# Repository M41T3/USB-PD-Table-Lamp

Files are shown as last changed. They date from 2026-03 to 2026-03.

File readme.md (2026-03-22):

# Table Lamp with USB PD Light Controller

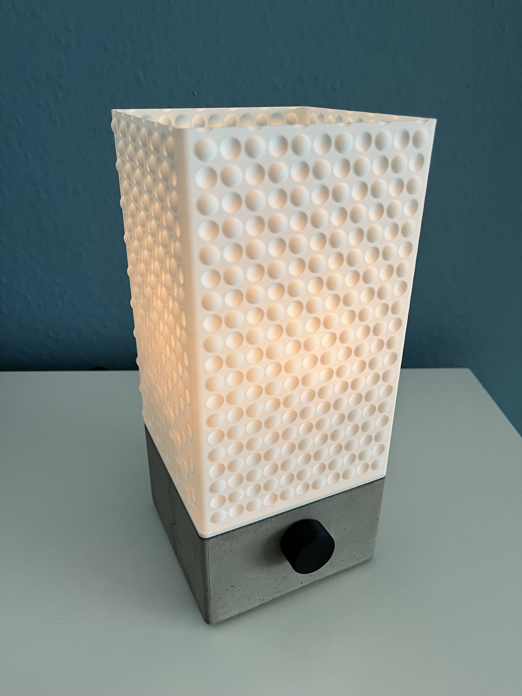
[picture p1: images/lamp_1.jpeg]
lamp


## Contents

- Light controller PCB design
    - [Schematics](light_controller_pcb/light_controller_base/schematics.pdf)
    - [PCB design](light_controller_pcp/light_controller_base/pcb.pdf)
    - KiCad project
    - JLCPCB production files
- CAD designs (FreeCAD projects)
    - concrete lamp base mould
    - shade, light mount and knob

## 1. PCB design

The objective was to develop a highly configurable controller for various light sources that is powered via USB Power Delivery.

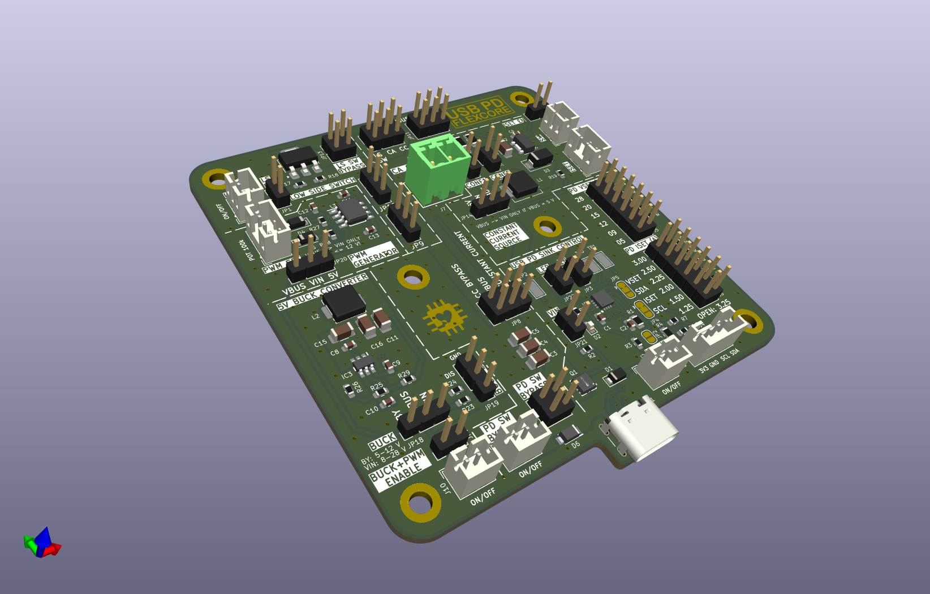
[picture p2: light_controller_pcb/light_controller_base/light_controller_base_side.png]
pcb


### Operation Modes

The operating mode can be configured using jumpers and potentiomenter wiring: 

1. Switch VBUS power and dimm light via PMW
2. Switch VBUS power and dimm light via constant current source
3. Low Side Switch and dimm light via PWM
4. Simple ON/OFF with disabled USB PD (5 V)
5. Switch VBUS power and fixed output current (set with jumpers)

### Noteable Features
- Configure output voltage and current 
    - Voltage: 5 V, 9 V, 12 V, 15 V, 20 V, 28 V
    - Current: 1.25 A - 3.25 A
    - Low power LED up to high power halogen lamps (35 W) supported
- Step-down converter to supply control units with all voltage levels
- Dimm light with PWM (555 Timer module)
- Constant current source to fine tune current 
- High power mosfet to switch light 
- 80 x 80 mm

#### USB PD ERP Sink controller ([HUSB238A](https://www.lcsc.com/datasheet/C24833806.pdf)):

- Fully Autonomous USB Type-C® and USB PD Sink Controller
- USB PD Specification Reversion 3.1 supported
- Integrated VBUS Switch Driver
- Error detection output (LED)

#### PWM Controller ([LMC555](https://www.lcsc.com/datasheet/C90760.pdf))

- CMOS variant of famous 555 general-purpose timer
- Duty cycle configurable by 100k potentiometer 

#### Constant Current Source ([PAM2861](https://www.lcsc.com/datasheet/C150496.pdf))

- 1 A LED driber with internal switch
- Adjustable output current (100k potentiometer)

#### Step-Down Converter ([TPS54302](https://www.ti.com/lit/ds/symlink/tps54302.pdf))

- Converts variable VUSB voltage to 5 V to supply 555 timer and constant current control

#### 100 kOhm Potentiometer with Rotary Switch ([WSFA202-A2-08-30F1](https://asset.conrad.com/media10/add/160267/c1/-/en/000441431DS01/tehnicni-podatki-441431-potenciometer-z-10-a-stikalomweltron-wsfa202-a2-08-30f1-10k-20-lin-10-kiloo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))

## 2. Concrete Lamp Base

The lamp's base was made of concrete. To do this, a mold was designed and printed using a 3D printer with PLA. The controller board is installed inside the lamp's base.

### Mould

The mold is designed so that it can be taken apart into separate pieces after curing.

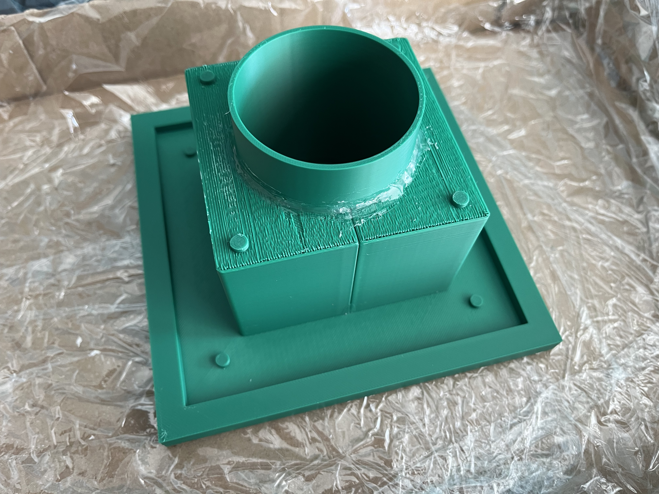
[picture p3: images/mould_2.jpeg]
inner mould


The seams are sealed with hot glue.

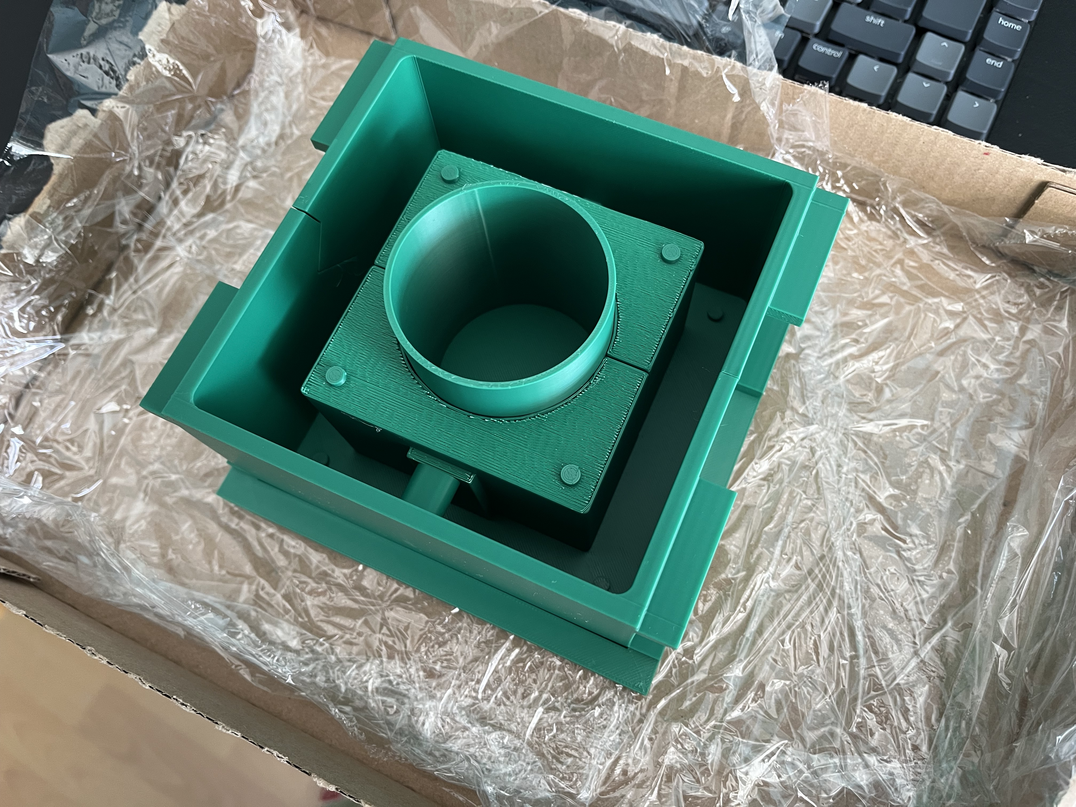
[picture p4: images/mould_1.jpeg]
complete mould


The liquid concrete is poured into the mold up to the top edge:

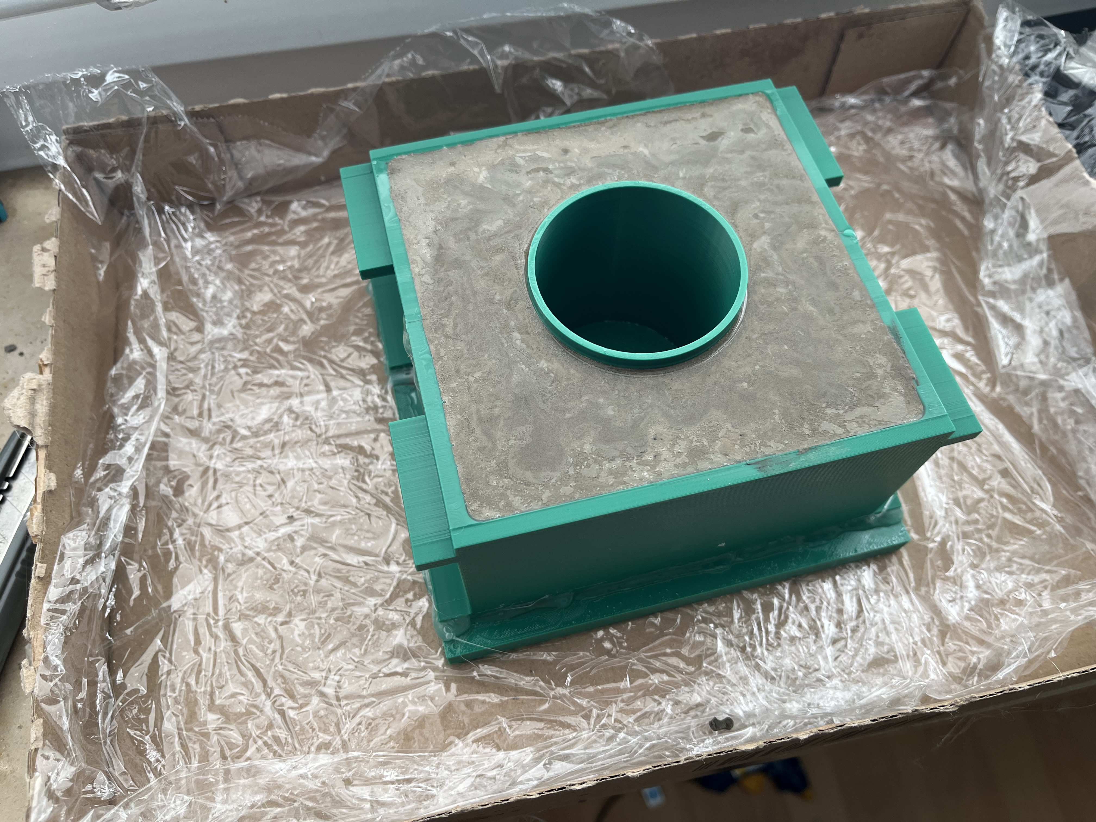
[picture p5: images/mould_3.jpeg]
filled mould


### Box of Shame
To be honest, it took three attempts with different modifications to the base design before I was able to get the concrete piece out of the mold in one piece...

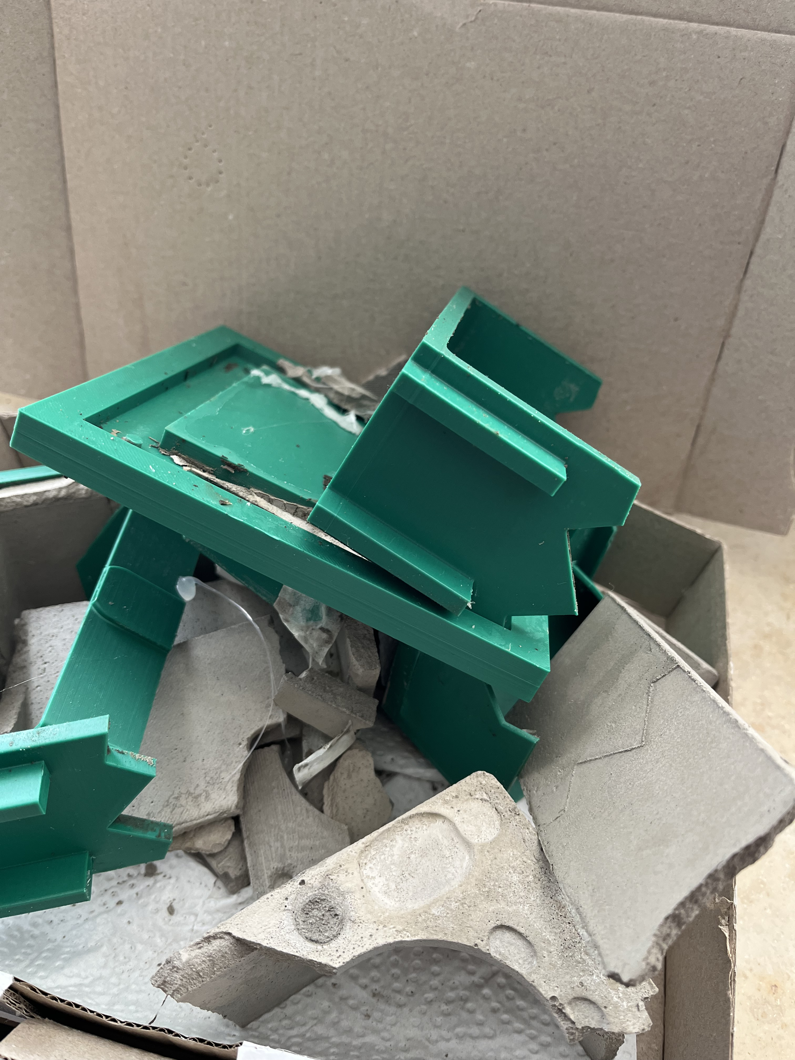
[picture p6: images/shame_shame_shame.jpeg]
box of shame


### Base installations

To position the light source in the right spot, a 3D-printed bracket is screwed onto the circuit board: 

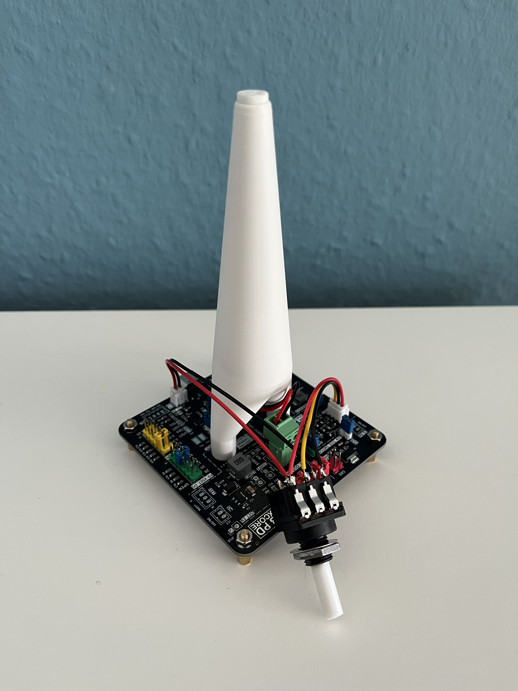
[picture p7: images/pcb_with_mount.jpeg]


PCB, potentiomenter, knob and magnets are installed to the base:

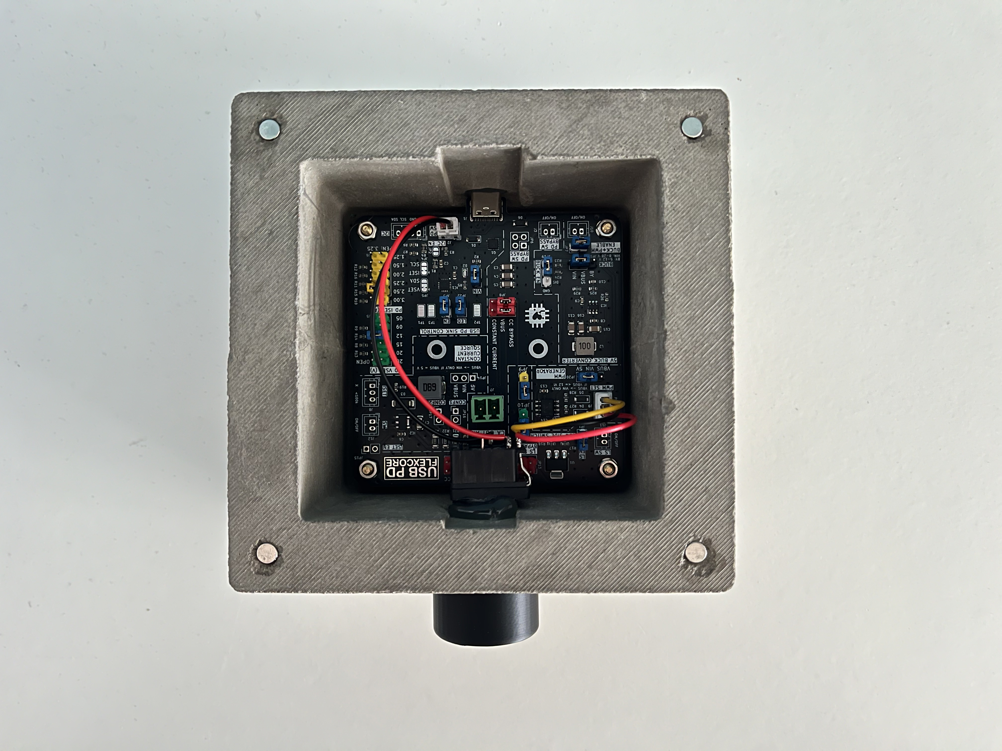
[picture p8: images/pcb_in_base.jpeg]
pcb in base


Bottom: 

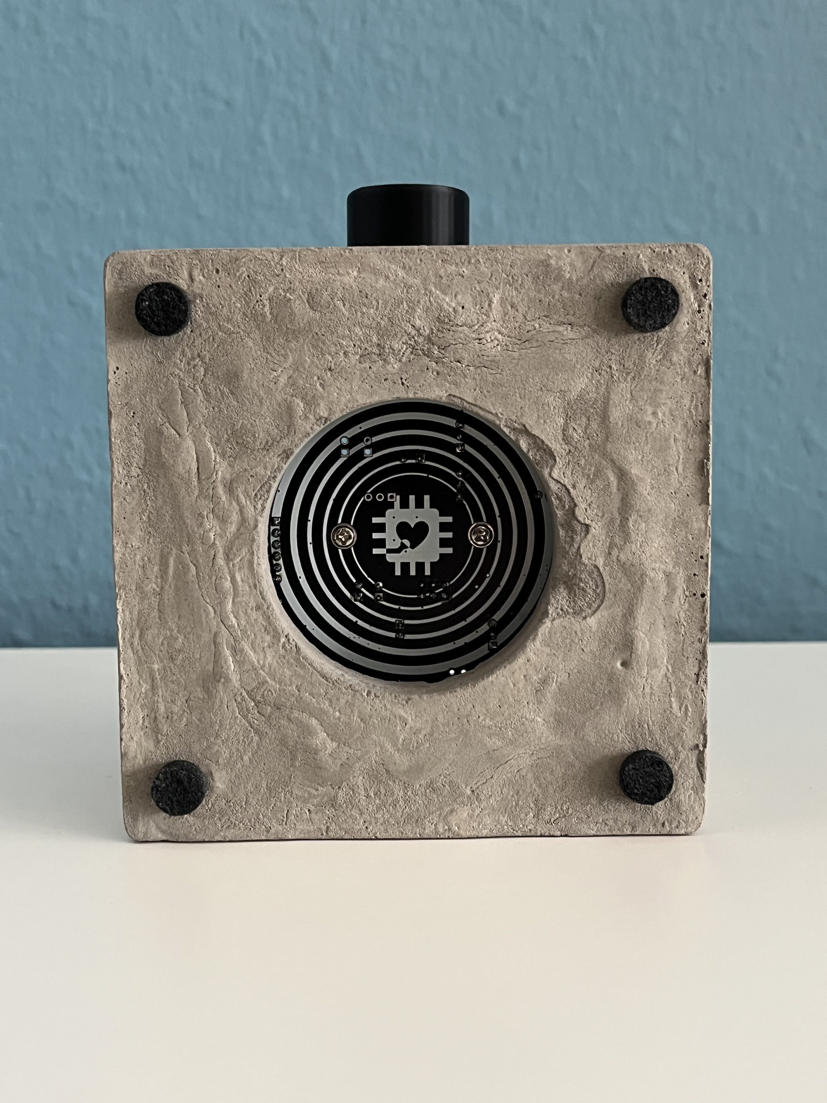
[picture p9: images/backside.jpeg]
pcb backside


## 3. Shade

The lamp base was designed so that the light shade can be attached using magnets. This means the shade can be easily swapped out. This shade was designed so that it can be 3D-printed in vase mode.

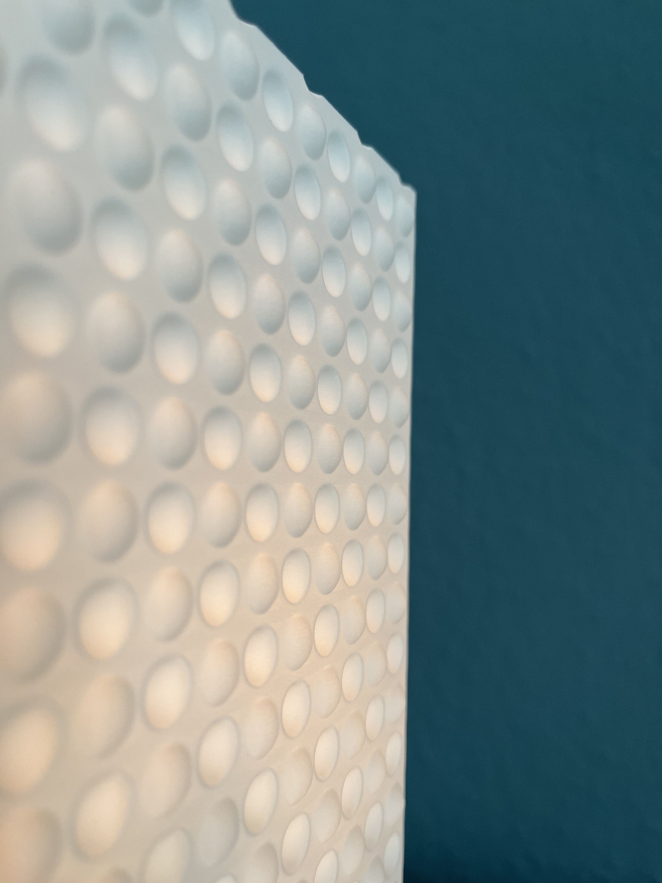
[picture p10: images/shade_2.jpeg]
shade

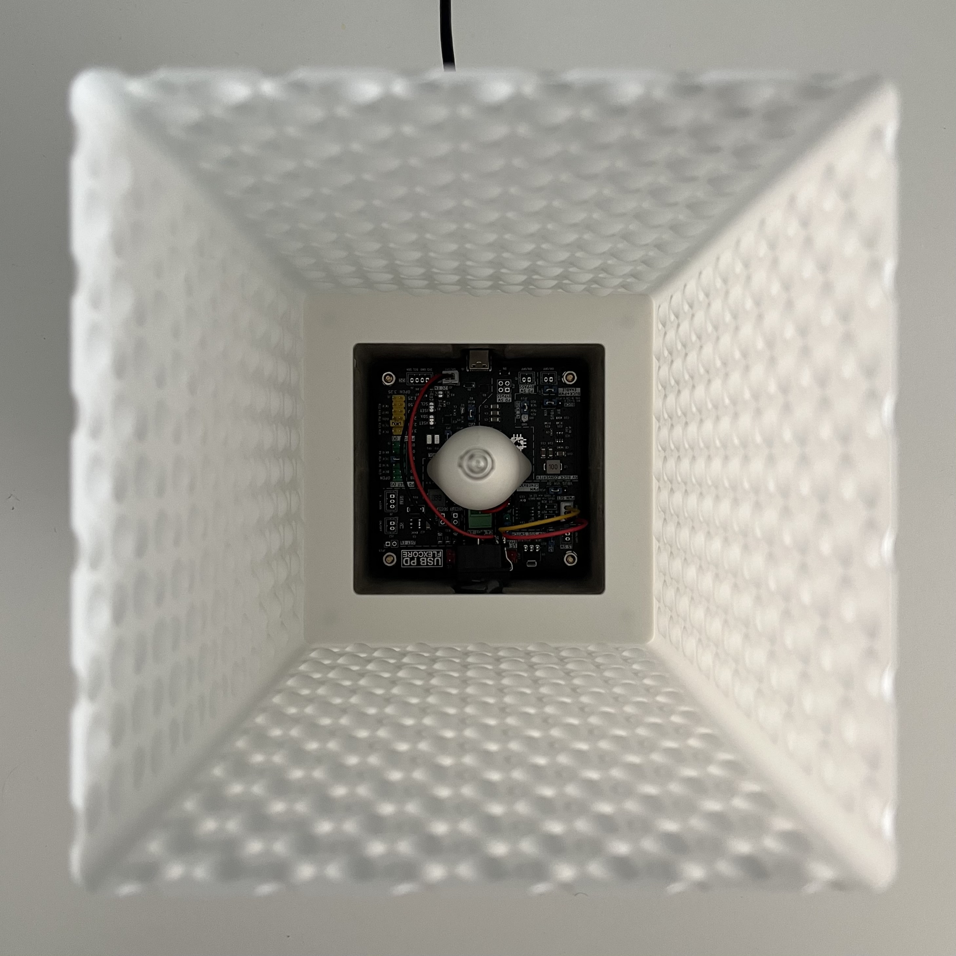
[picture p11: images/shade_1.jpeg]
shade detailed


## 4. Light it up!

Operating Mode: Switch VBUS and dimm light via PWM with potentiometer

lamp gif

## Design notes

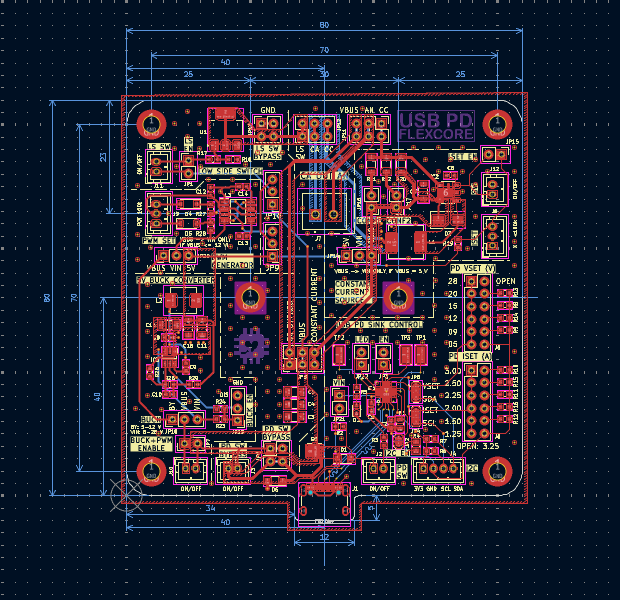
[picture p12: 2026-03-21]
light_controller_pcb/light_controller_base/pcb_design.png

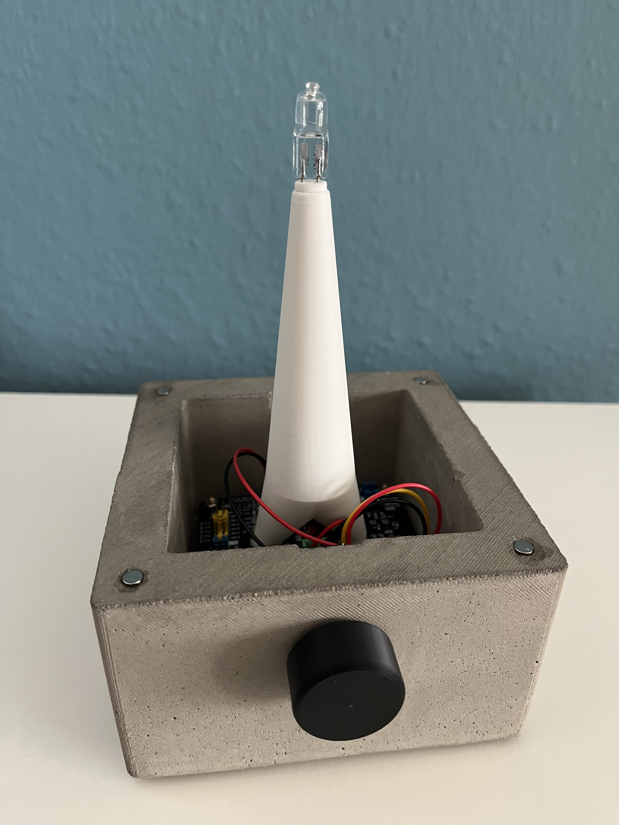
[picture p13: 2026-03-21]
images/lamp_wo_shade.jpeg

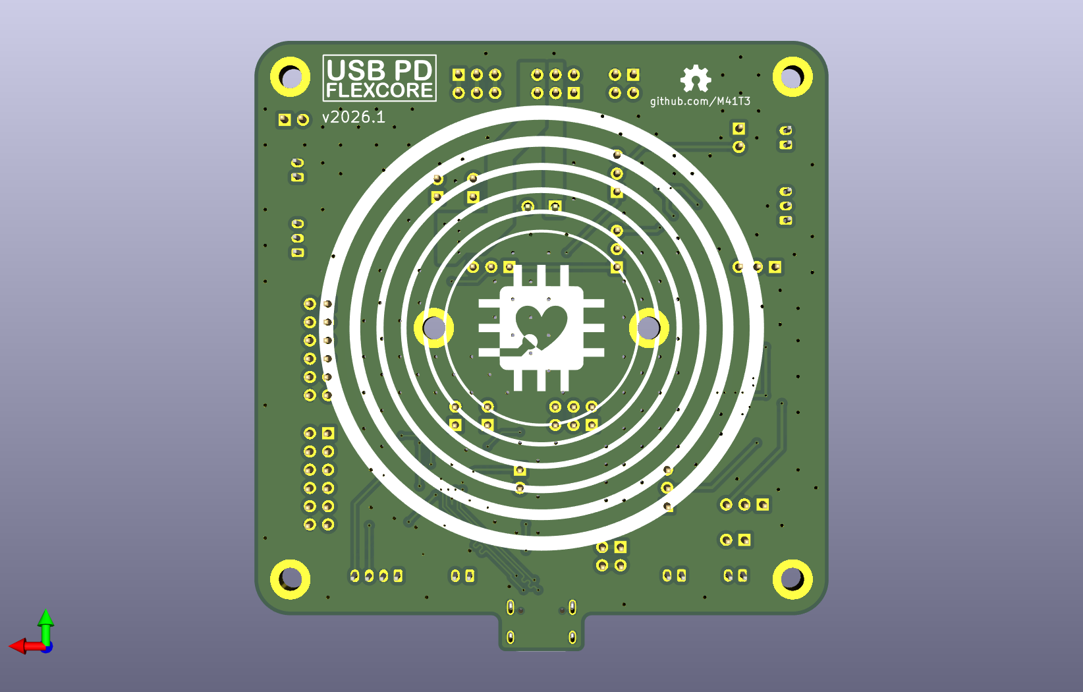
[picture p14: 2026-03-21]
light_controller_pcb/light_controller_base/light_controller_base_bottom.png

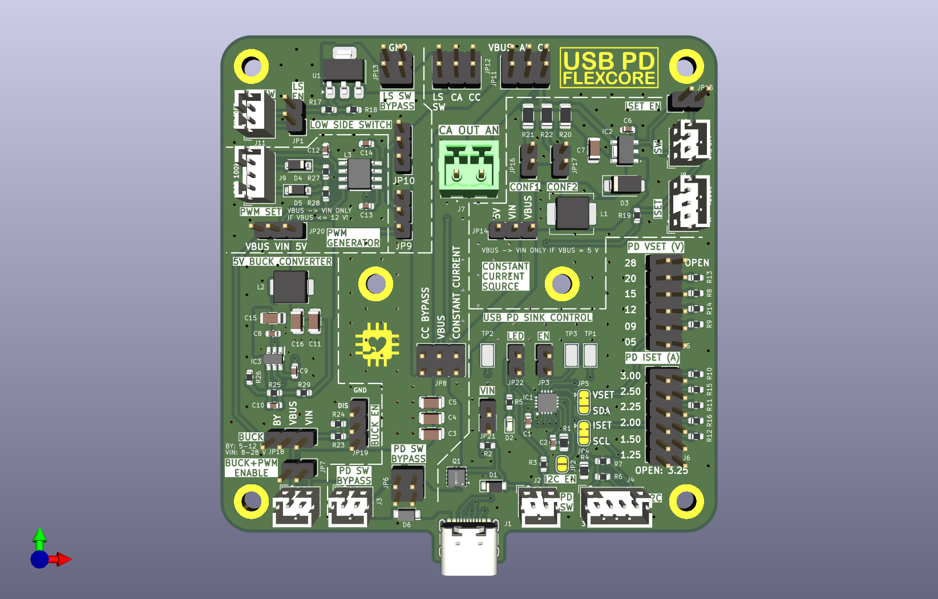
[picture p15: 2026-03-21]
light_controller_pcb/light_controller_base/light_controller_base_top.png

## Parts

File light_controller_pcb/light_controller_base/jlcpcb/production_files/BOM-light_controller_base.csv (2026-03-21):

Comment | Designator | Footprint | LCSC | Quantity
0.1 uF | C14 | C_0603_1608Metric | C14663 | 1
0.3 | R20,R21,R22 | R_1206_3216Metric | C59882 | 3
1 uF | C1,C2 | C_0603_1608Metric | C15849 | 2
1.8k | R5 | R_0603_1608Metric | C4177 | 1
10 nF | C12,C13 | C_0603_1608Metric | C57112 | 2
10 uF | C15,C7 | C_1206_3216Metric | C13585 | 2
10 uH | L2 | L_5.2_5.4_smd | C351099 | 1
100 nF | C8,C9 | C_0603_1608Metric | C14663 | 2
100k | R19,R25 | R_0603_1608Metric | C25803 | 2
105k | R24 | R_0603_1608Metric | C16840 | 1
10k | R6,R7 | R_0603_1608Metric | C25804 | 2
10nF | C6 | C_0603_1608Metric | C57112 | 1
11.5k | R15 | R_0603_1608Metric | C25949 | 1
11k | R8 | R_0603_1608Metric | C25950 | 1
13.3k | R26 | R_0603_1608Metric | C25952 | 1
19.1k | R13 | R_0603_1608Metric | C22897 | 1
1k | R17,R27,R28 | R_0603_1608Metric | C21190 | 3
2.26k | R12 | R_0603_1608Metric | C22904 | 1
21k | R10 | R_0603_1608Metric | C22956 | 1
22 uF | C11,C16 | C_1206_3216Metric | C12891 | 2
3k | R9 | R_0603_1608Metric | C4211 | 1
4.7 uF | C3,C4,C5 | C_1206_3216Metric | C29823 | 3
49.9 | R29 | R_0603_1608Metric | C23185 | 1
49.9k | R18,R2 | R_0603_1608Metric | C23184 | 2
511k | R23 | R_0603_1608Metric | C23194 | 1
6.04k | R14,R16 | R_0603_1608Metric | C25977 | 2
6.2k | R3 | R_0603_1608Metric | C4260 | 1
68 uH | L1 | L_6.6_7.1_smd | C2983094 | 1
75 pF | C10 | C_0603_1608Metric | C1681 | 1
8.45k | R11 | R_0603_1608Metric | C163417 | 1
900k | R1,R4 | R_0805_2012Metric | C52209984 | 2
AONR21307 | Q1 | DFN_3X3_EP | C3277813 | 1
D_Small | D4,D5 | D_SOD-123 | C81598 | 2
LMC555CMX_NOPB | L3 | SOIC127P600X175-8N | C90760 | 1
MM1Z24W Zener 24V | D1 | Nexperia_CFP3_SOD-123W | C2856870 | 1
NCE6005AR custom | U1 | SOT-223-3_TabPin2 | C189606 | 1
PAM2861CBR | IC2 | SOT89-5 | C150496 | 1
SMF33A | D6 | SODFL3618X110N | C353288 | 1
SS14 | D3 | D_SMA | C2480 | 1
TPS54302DDCR | IC3 | SOT95P280X110-6N | C311983 | 1
USB_C_Receptacle_USB2.0_16P | J1 | USB_C_Receptacle_GCT_USB4105-xx-A_16P_TopMnt_Horizontal | C165948 | 1
husb238a | IC1 | QFN50P300X300X80-17N-D | C24833806 | 1
~ | D2 | LED_0603_1608Metric | C2286 | 1

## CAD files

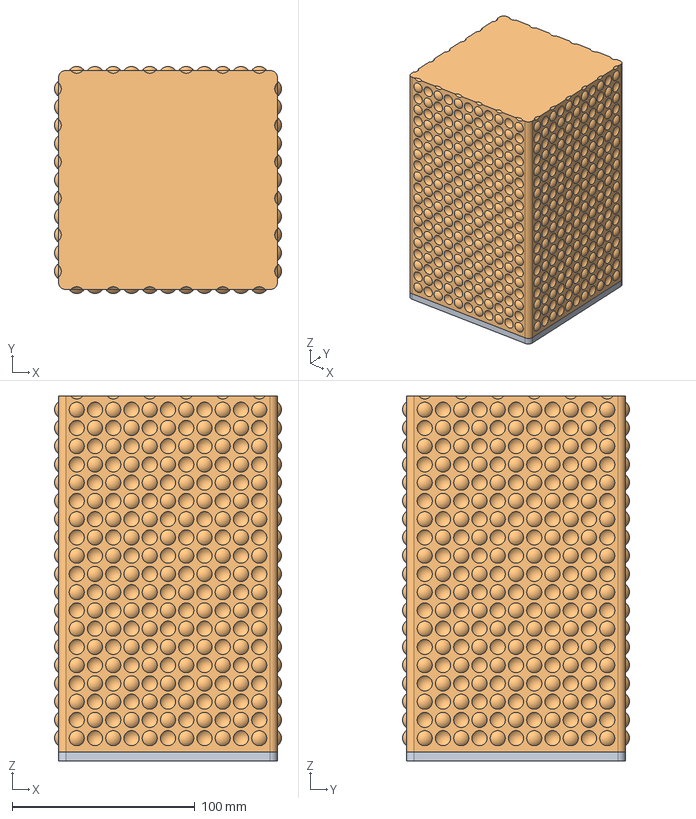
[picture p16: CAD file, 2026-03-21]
cad/shade_bubble_v2/shade_bubble_v2.step
124.4 x 124.4 x 200.0 mm
shade_base_w_mag

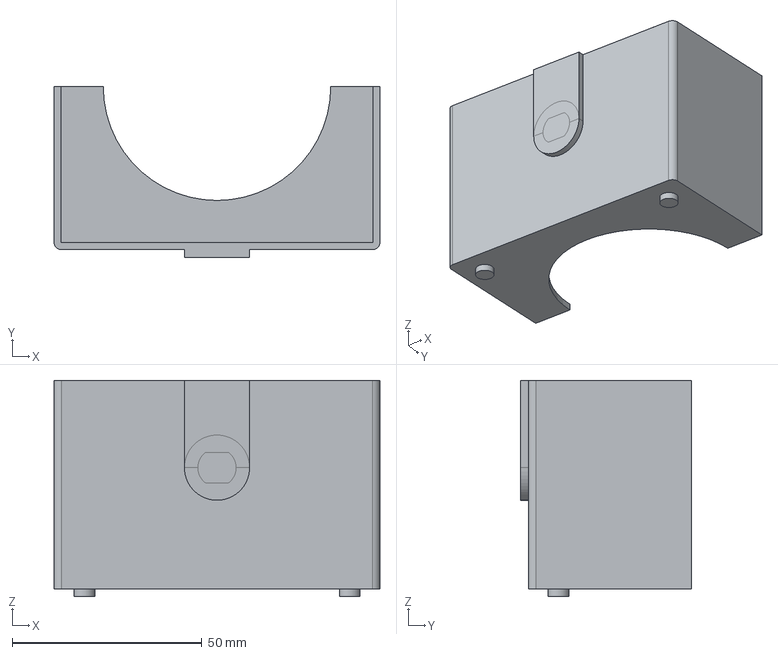
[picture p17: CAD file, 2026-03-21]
cad/usb_table_lamp-mould-mid-inf-thick.step
86.0 x 45.0 x 57.0 mm

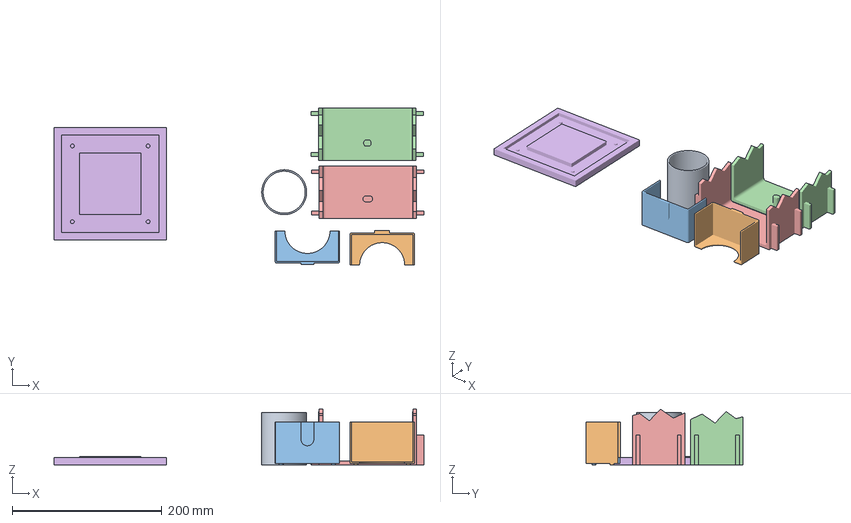
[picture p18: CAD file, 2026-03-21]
cad/usb_table_lamp-thick.3mf
493.5 x 209.8 x 74.3 mm
usb_table_lamp-mould-mid-cyl-thick.step
usb_table_lamp-mould-mid-inb-thick.step
usb_table_lamp-mould-mid-inf-thick.step
usb_table_lamp-mould-mid-b-thick.step
usb_table_lamp-mould-mid-thick.step
usb_table_lamp-mould--bot-thick.step

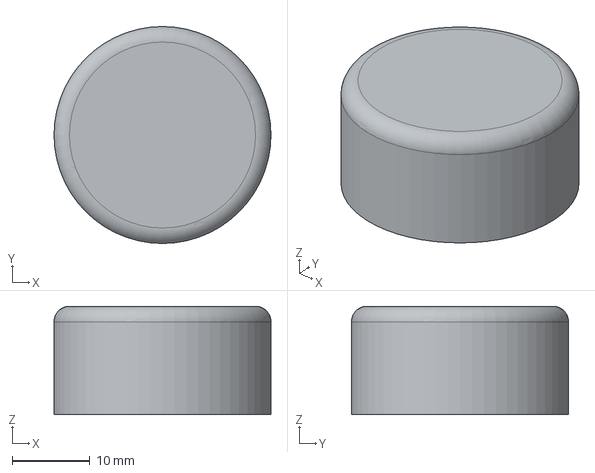
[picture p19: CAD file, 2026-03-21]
cad/usb_table_lamp-knob.step
28.0 x 28.0 x 14.0 mm

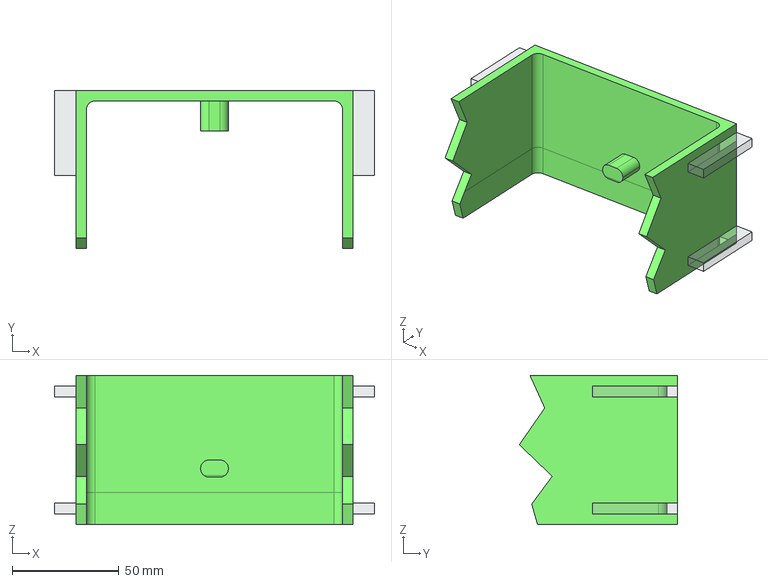
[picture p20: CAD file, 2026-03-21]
cad/usb_table_lamp-mould-mid-thick.step
150.0 x 74.3 x 70.0 mm

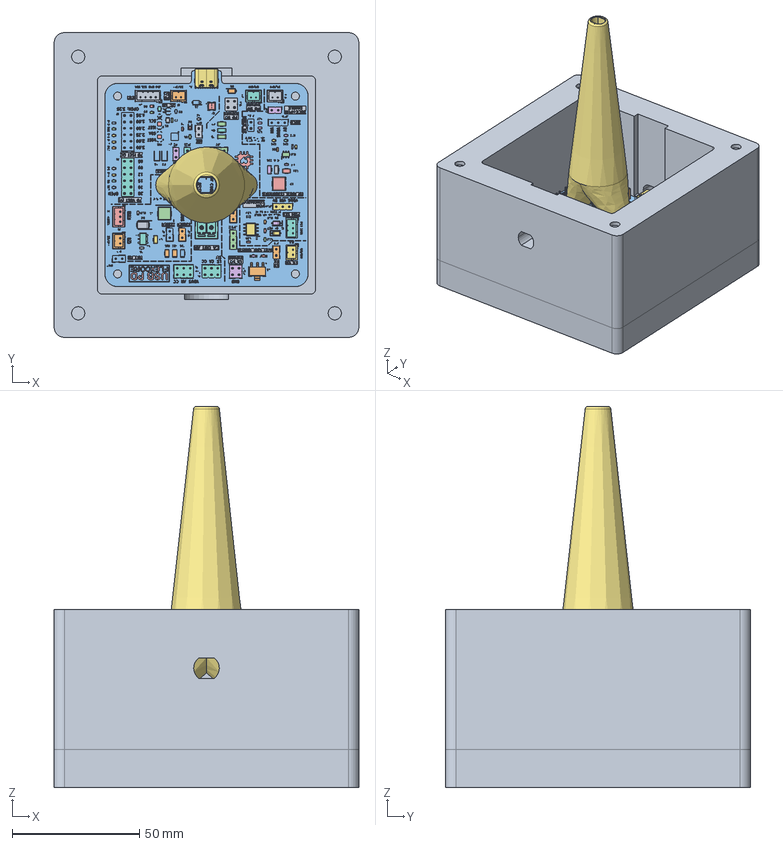
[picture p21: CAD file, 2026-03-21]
cad/usb_table_lamp.FCStd
120.0 x 120.0 x 150.0 mm
concrete_base_mhs
C_0603_1608Metric
C_0603_1608Metric001
PinHeader_1x03_P2.54mm_Vertical
C_0603_1608Metric002
PinHeader_1x02_P2.54mm_Vertical
R_0603_1608Metric
R_0603_1608Metric001
C_1206_3216Metric
R_1206_3216Metric
PinHeader_1x02_P2.54mm_Vertical001
C_1206_3216Metric001
R_0603_1608Metric002
R_0603_1608Metric003
R_0603_1608Metric004
PAM2861CBR
JST_PH_B4B-PH-K_1x04_P2.00mm_Vertical
PinKIdent
PinK
PinA
PinHeader_1x02_P2.54mm_Vertical002
R_0603_1608Metric005
PinHeader_1x02_P2.54mm_Vertical003
R_0603_1608Metric006
JST_PH_B2B-PH-K_1x02_P2.00mm_Vertical
PinHeader_2x06_P2.54mm_Vertical
C_0603_1608Metric003
L_APV_APH0518
R_0603_1608Metric007
R_0603_1608Metric008
R_0805_2012Metric
JST_PH_B2B-PH-K_1x02_P2.00mm_Vertical001
PinHeader_1x02_P2.54mm_Vertical004
light_controller_base 1.31.1
C_1206_3216Metric002
AON7401
Alpha and Omega Logo
JST_PH_B2B-PH-K_1x02_P2.00mm_Vertical002
PinHeader_2x03_P2.54mm_Vertical
R_0805_2012Metric001
JST_PH_B2B-PH-K_1x02_P2.00mm_Vertical003
R_0603_1608Metric009
R_0603_1608Metric010
R_0603_1608Metric011
C_0603_1608Metric004
USB_C_Receptacle_GCT_USB4105-xx-A_16P_TopMnt_Horizontal
PinHeader_2x06_P2.54mm_Vertical001
R_0603_1608Metric012
SOT-223
R_0603_1608Metric013
R_0603_1608Metric014
C_0603_1608Metric005
PinHeader_2x02_P2.54mm_Vertical
R_0603_1608Metric015
C_1206_3216Metric003
D_SMA
R_0603_1608Metric016
PinHeader_1x03_P2.54mm_Vertical001
PinHeader_2x03_P2.54mm_Vertical001
R_0603_1608Metric017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

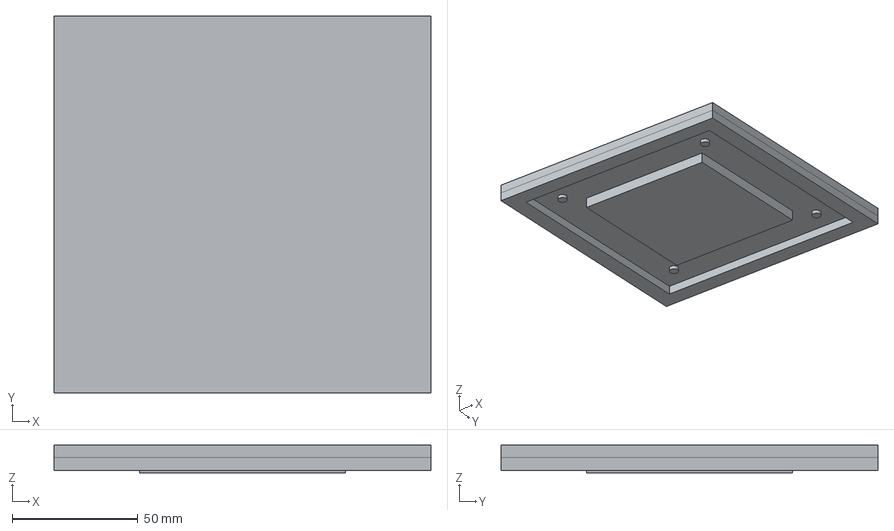
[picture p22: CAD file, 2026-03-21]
cad/usb_table_lamp-mould--bot-thick.step
150.0 x 150.0 x 11.0 mm

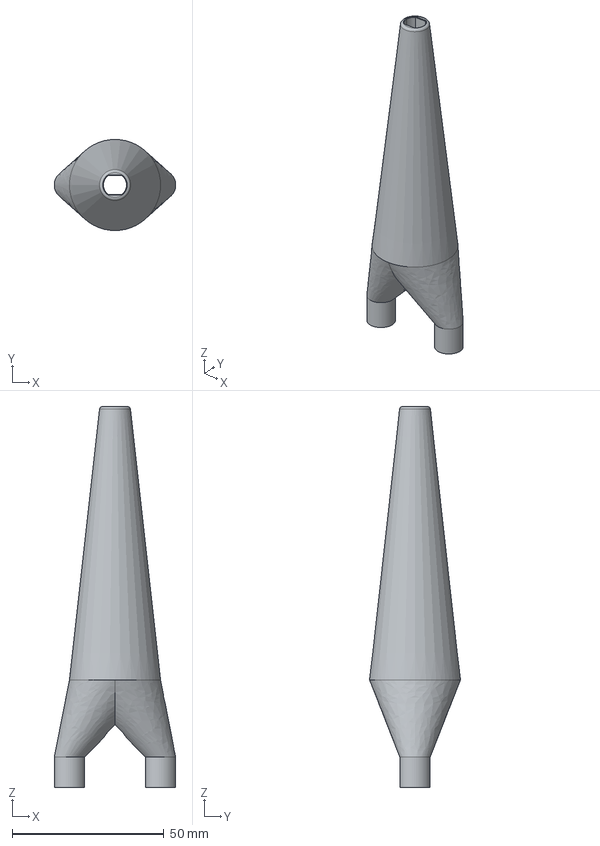
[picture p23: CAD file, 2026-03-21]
cad/usb_table_lamp-light_mount_v2.step
40.0 x 30.0 x 125.4 mm

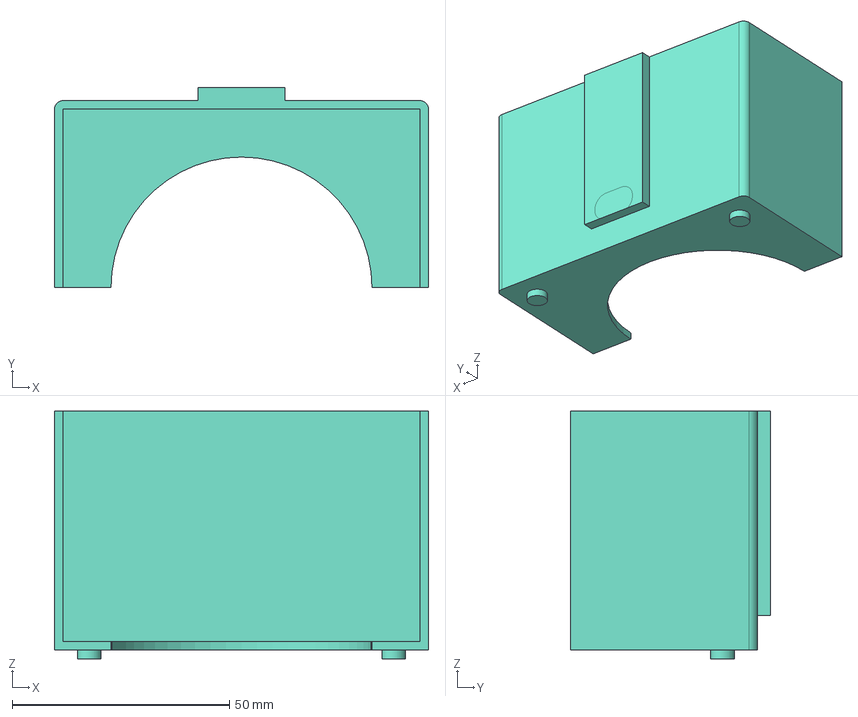
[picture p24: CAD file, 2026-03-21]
cad/usb_table_lamp-mould-mid-inb-thick.step
86.0 x 46.0 x 57.0 mm

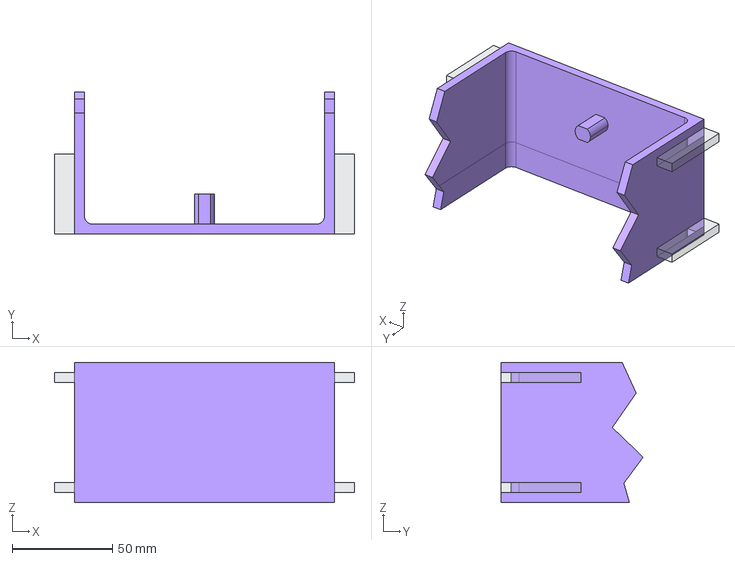
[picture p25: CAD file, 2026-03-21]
cad/usb_table_lamp-mould-mid-b-thick.step
150.0 x 71.2 x 70.0 mm

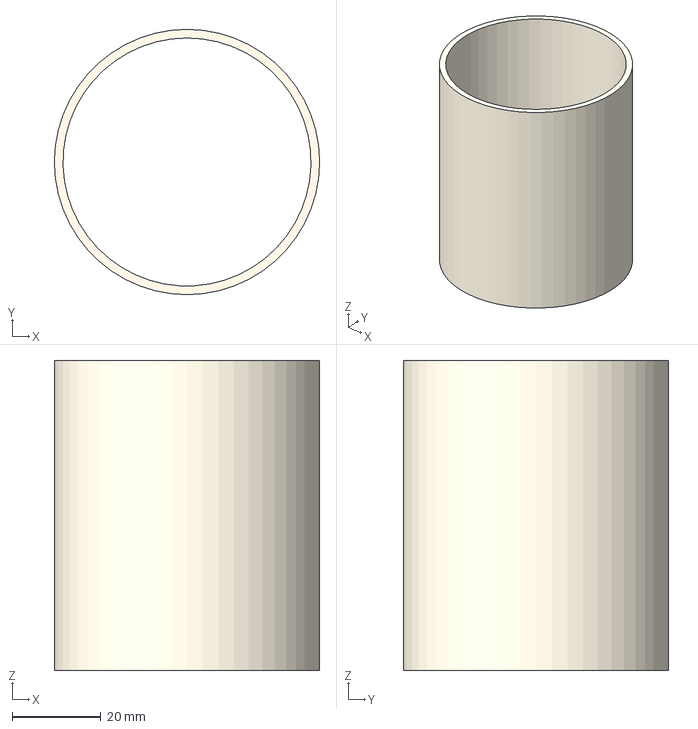
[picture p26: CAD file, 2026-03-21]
cad/usb_table_lamp-mould-mid-cyl-thick.step
59.9 x 59.9 x 70.0 mm

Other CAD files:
cad/usb_table_lamp-light_mount.step
cad/shade_bubble_v2/shade_bubble_v2.3mf
cad/shade_bubble_v2/shade_bubble_v2.FCStd
cad/usb_table_lamp-knob.3mf
cad/usb_table_lamp-mould-mid-cyl-thick.3mf

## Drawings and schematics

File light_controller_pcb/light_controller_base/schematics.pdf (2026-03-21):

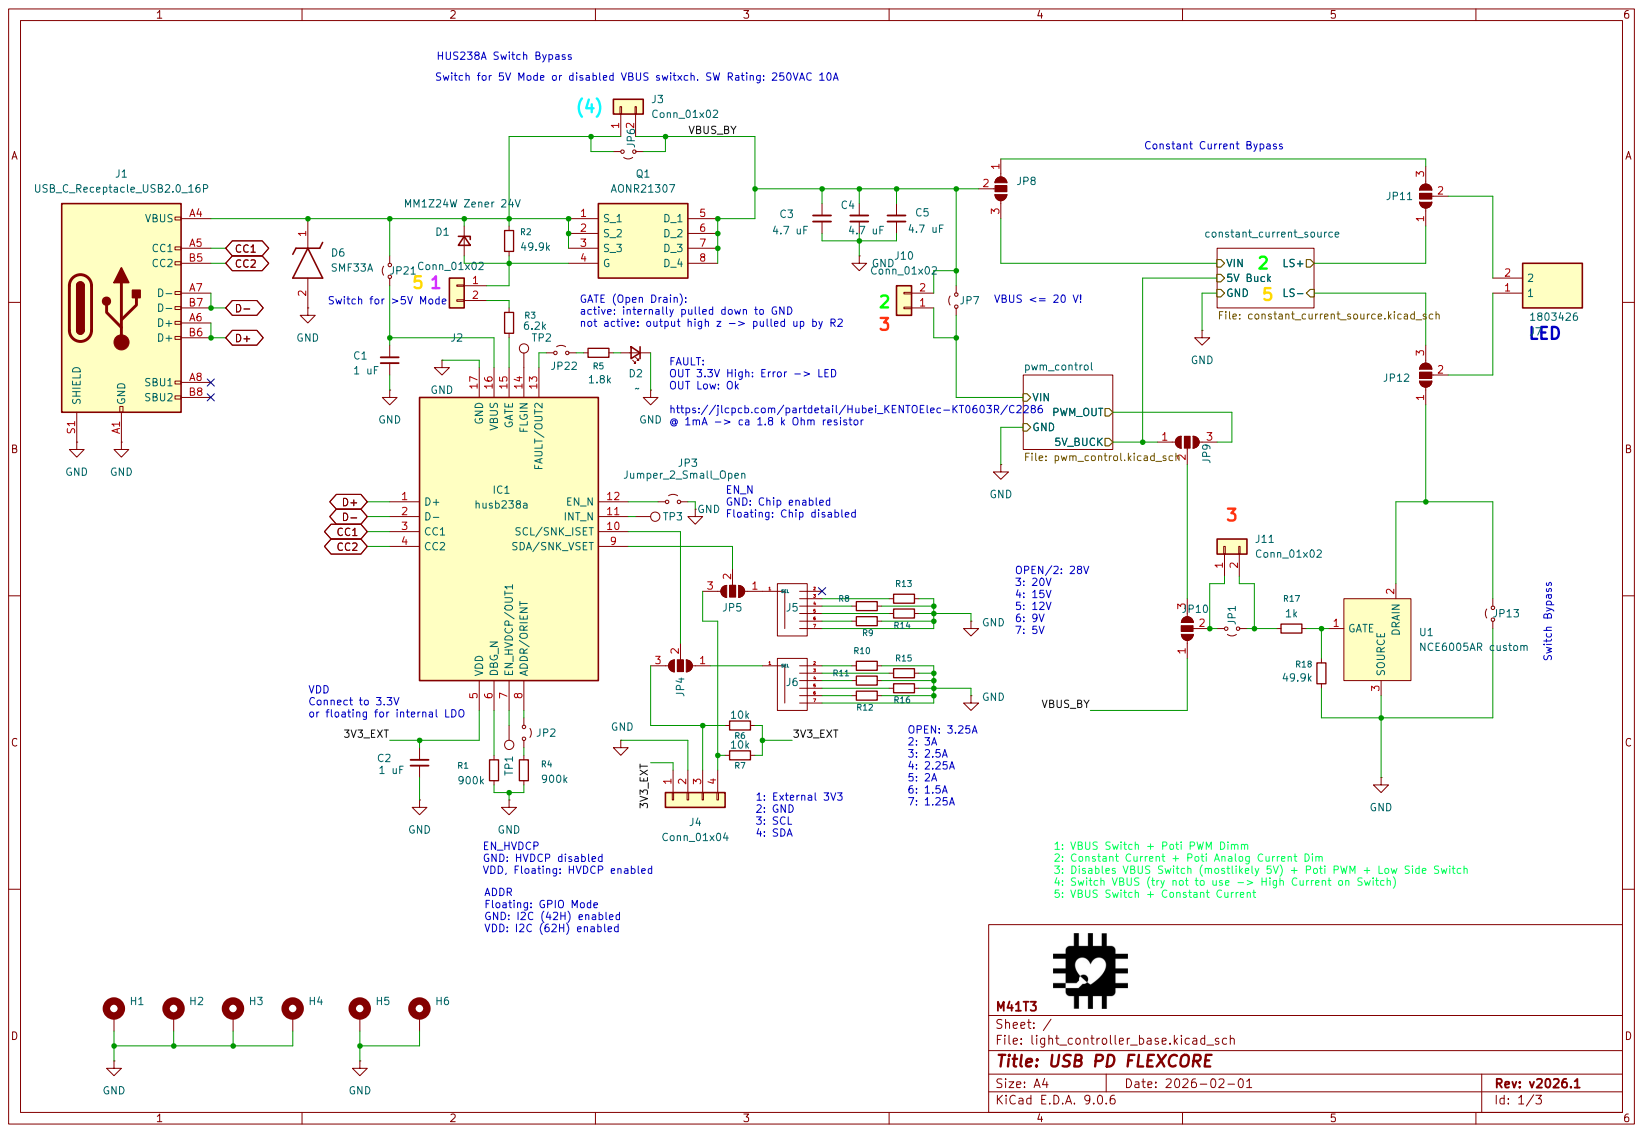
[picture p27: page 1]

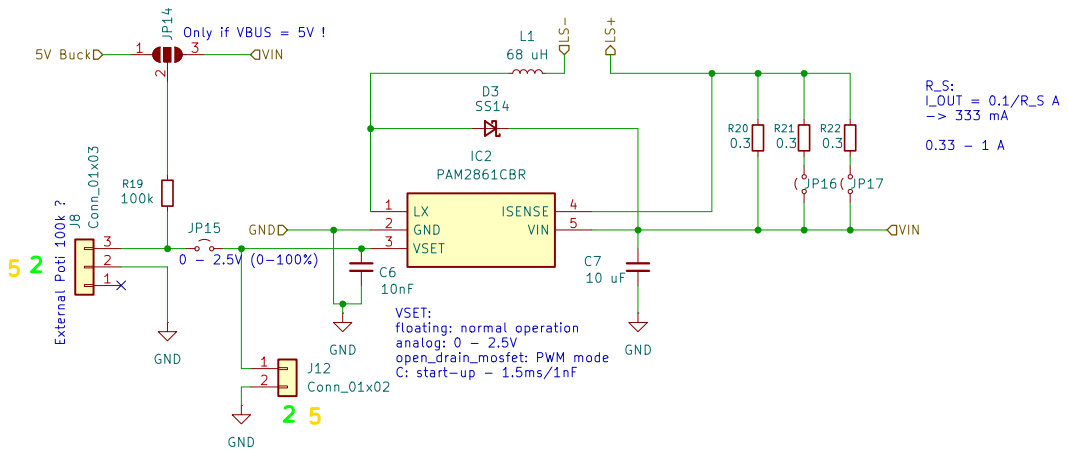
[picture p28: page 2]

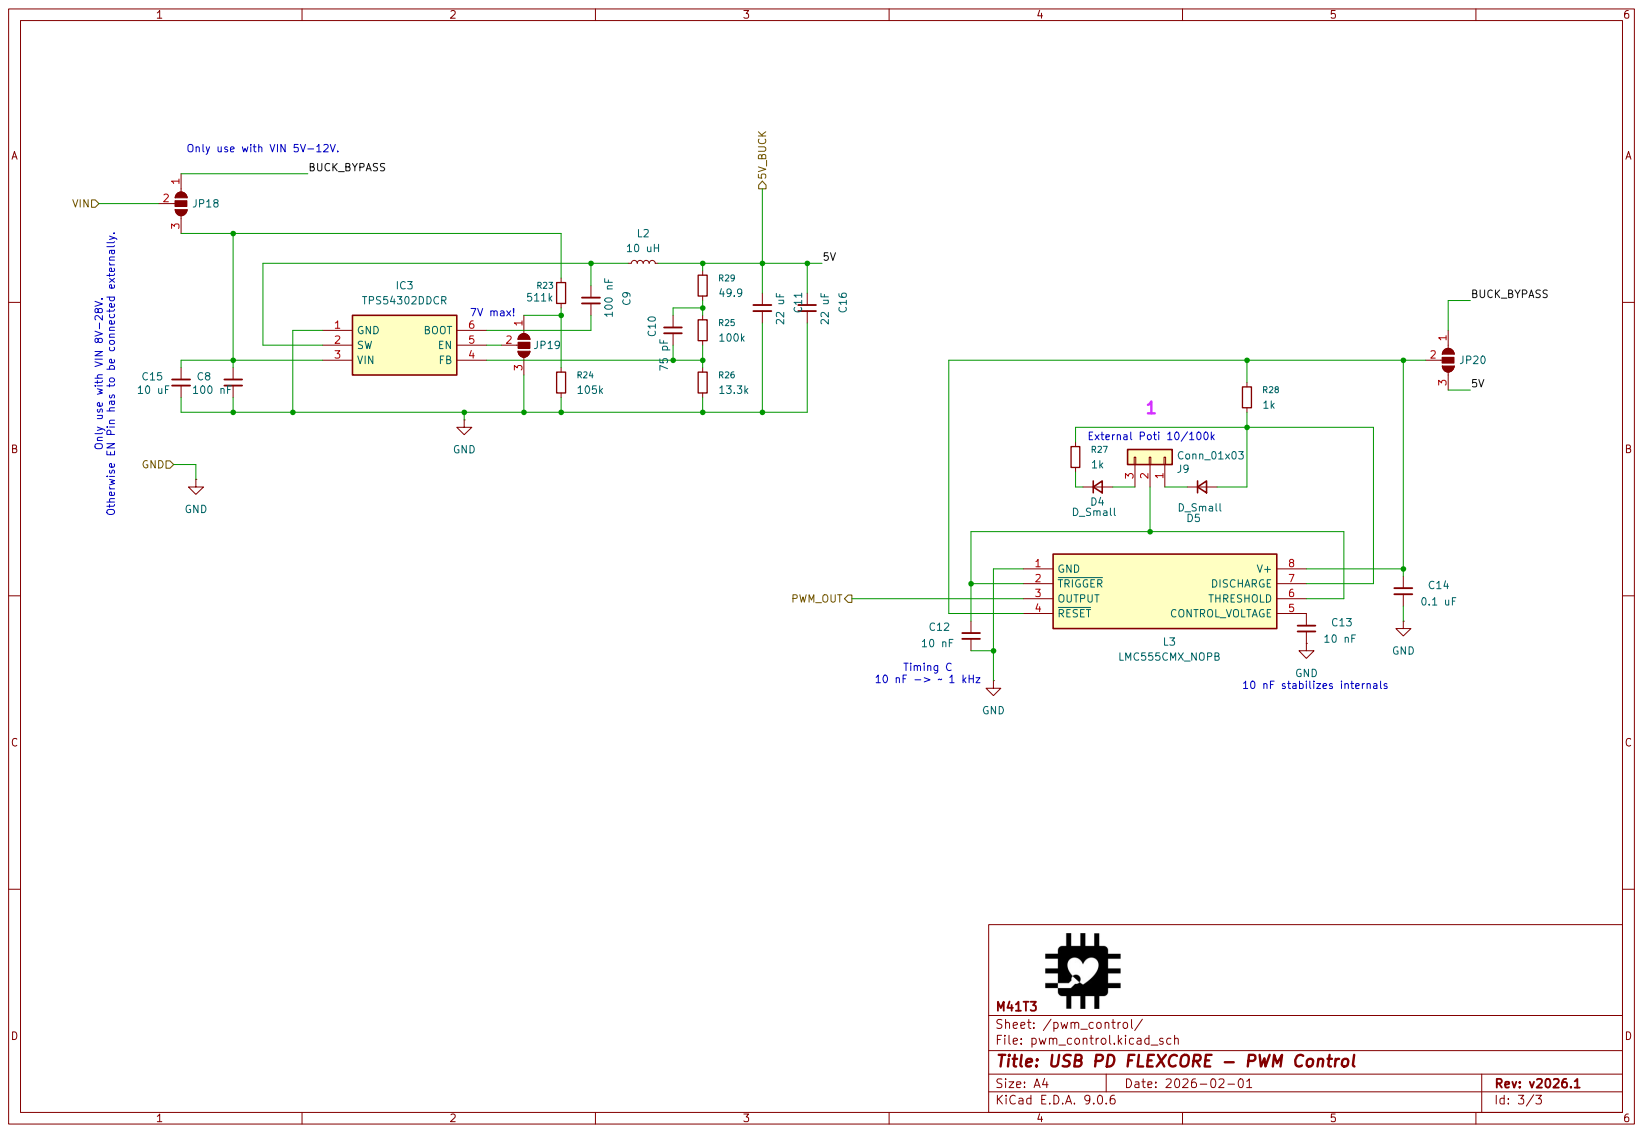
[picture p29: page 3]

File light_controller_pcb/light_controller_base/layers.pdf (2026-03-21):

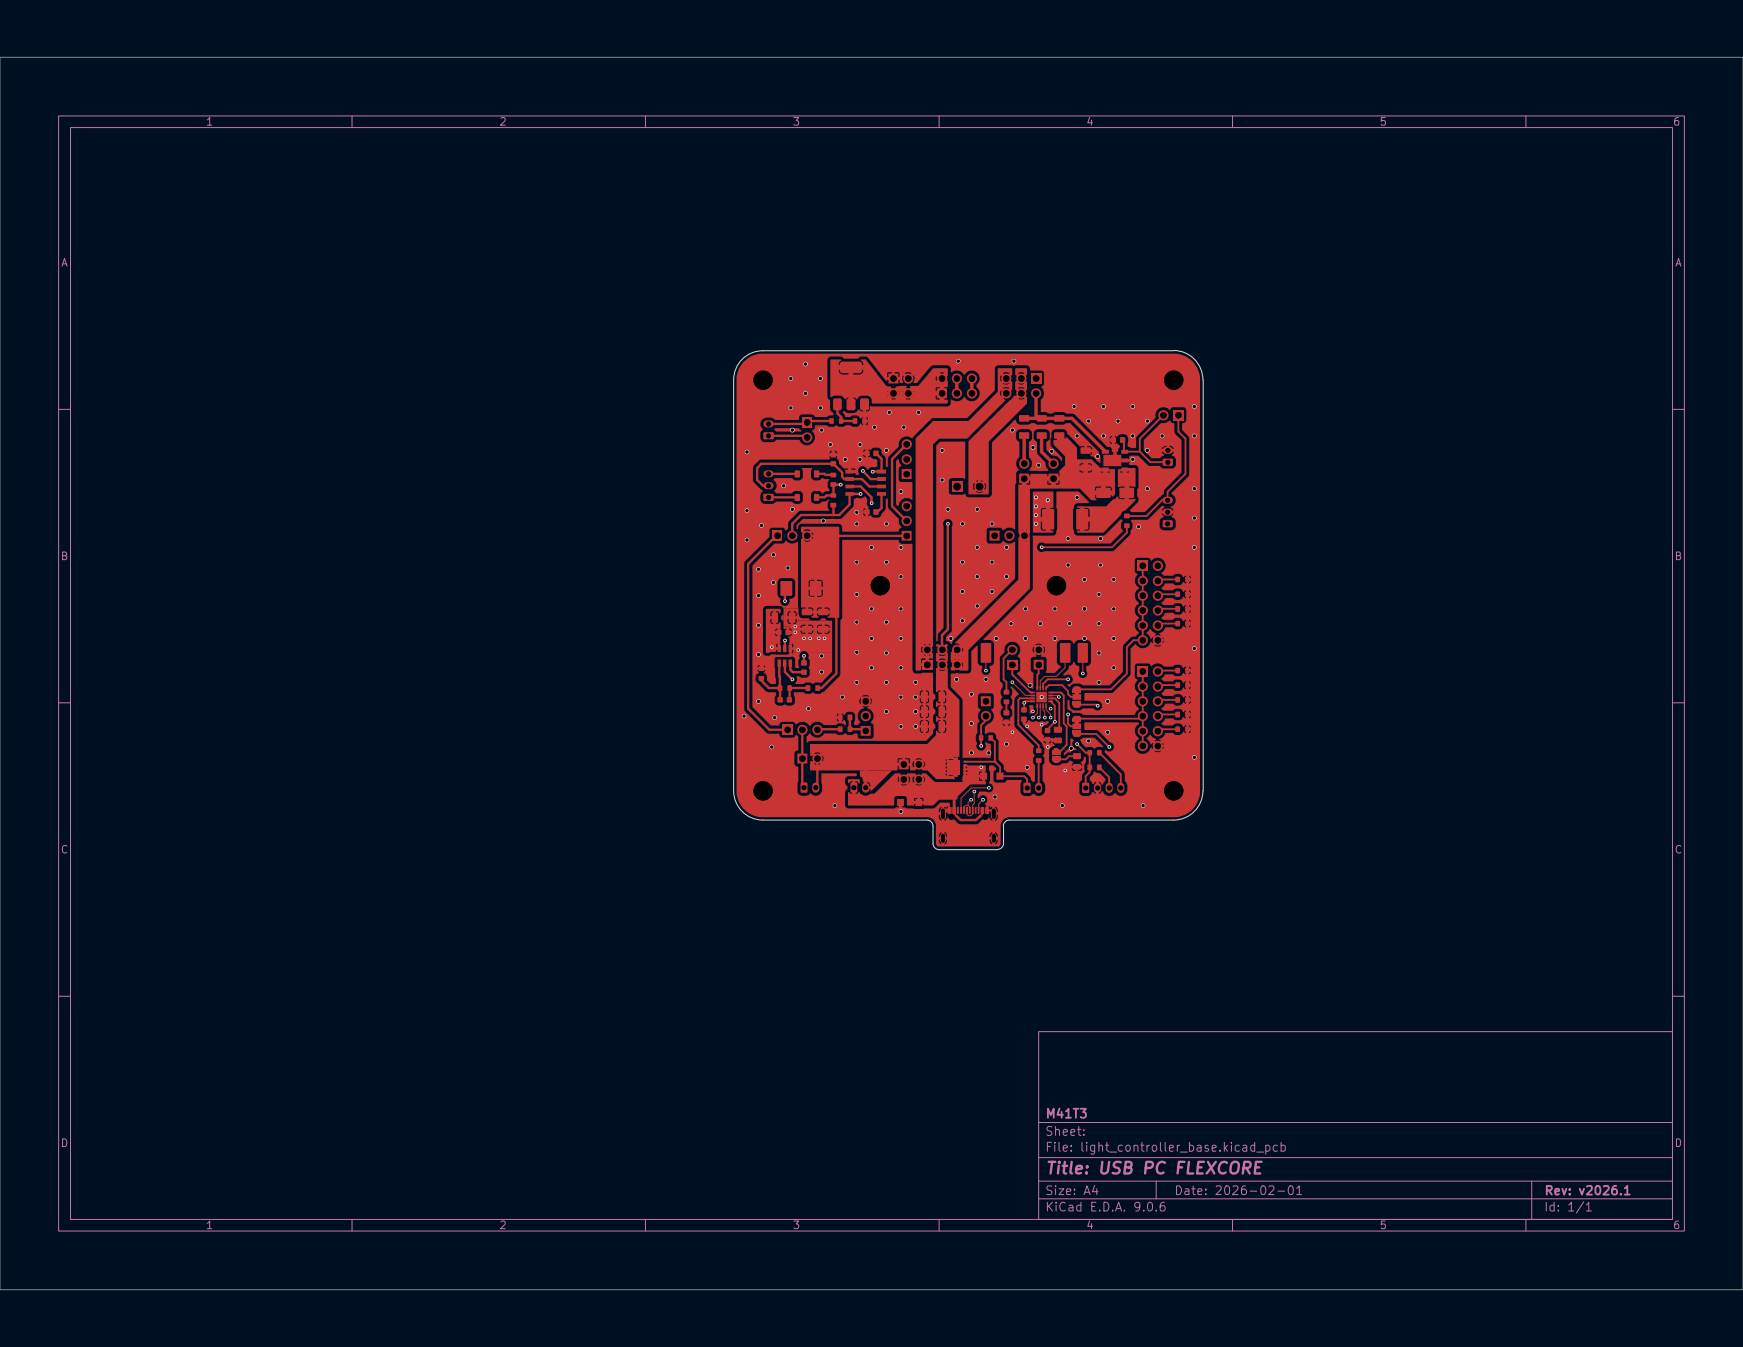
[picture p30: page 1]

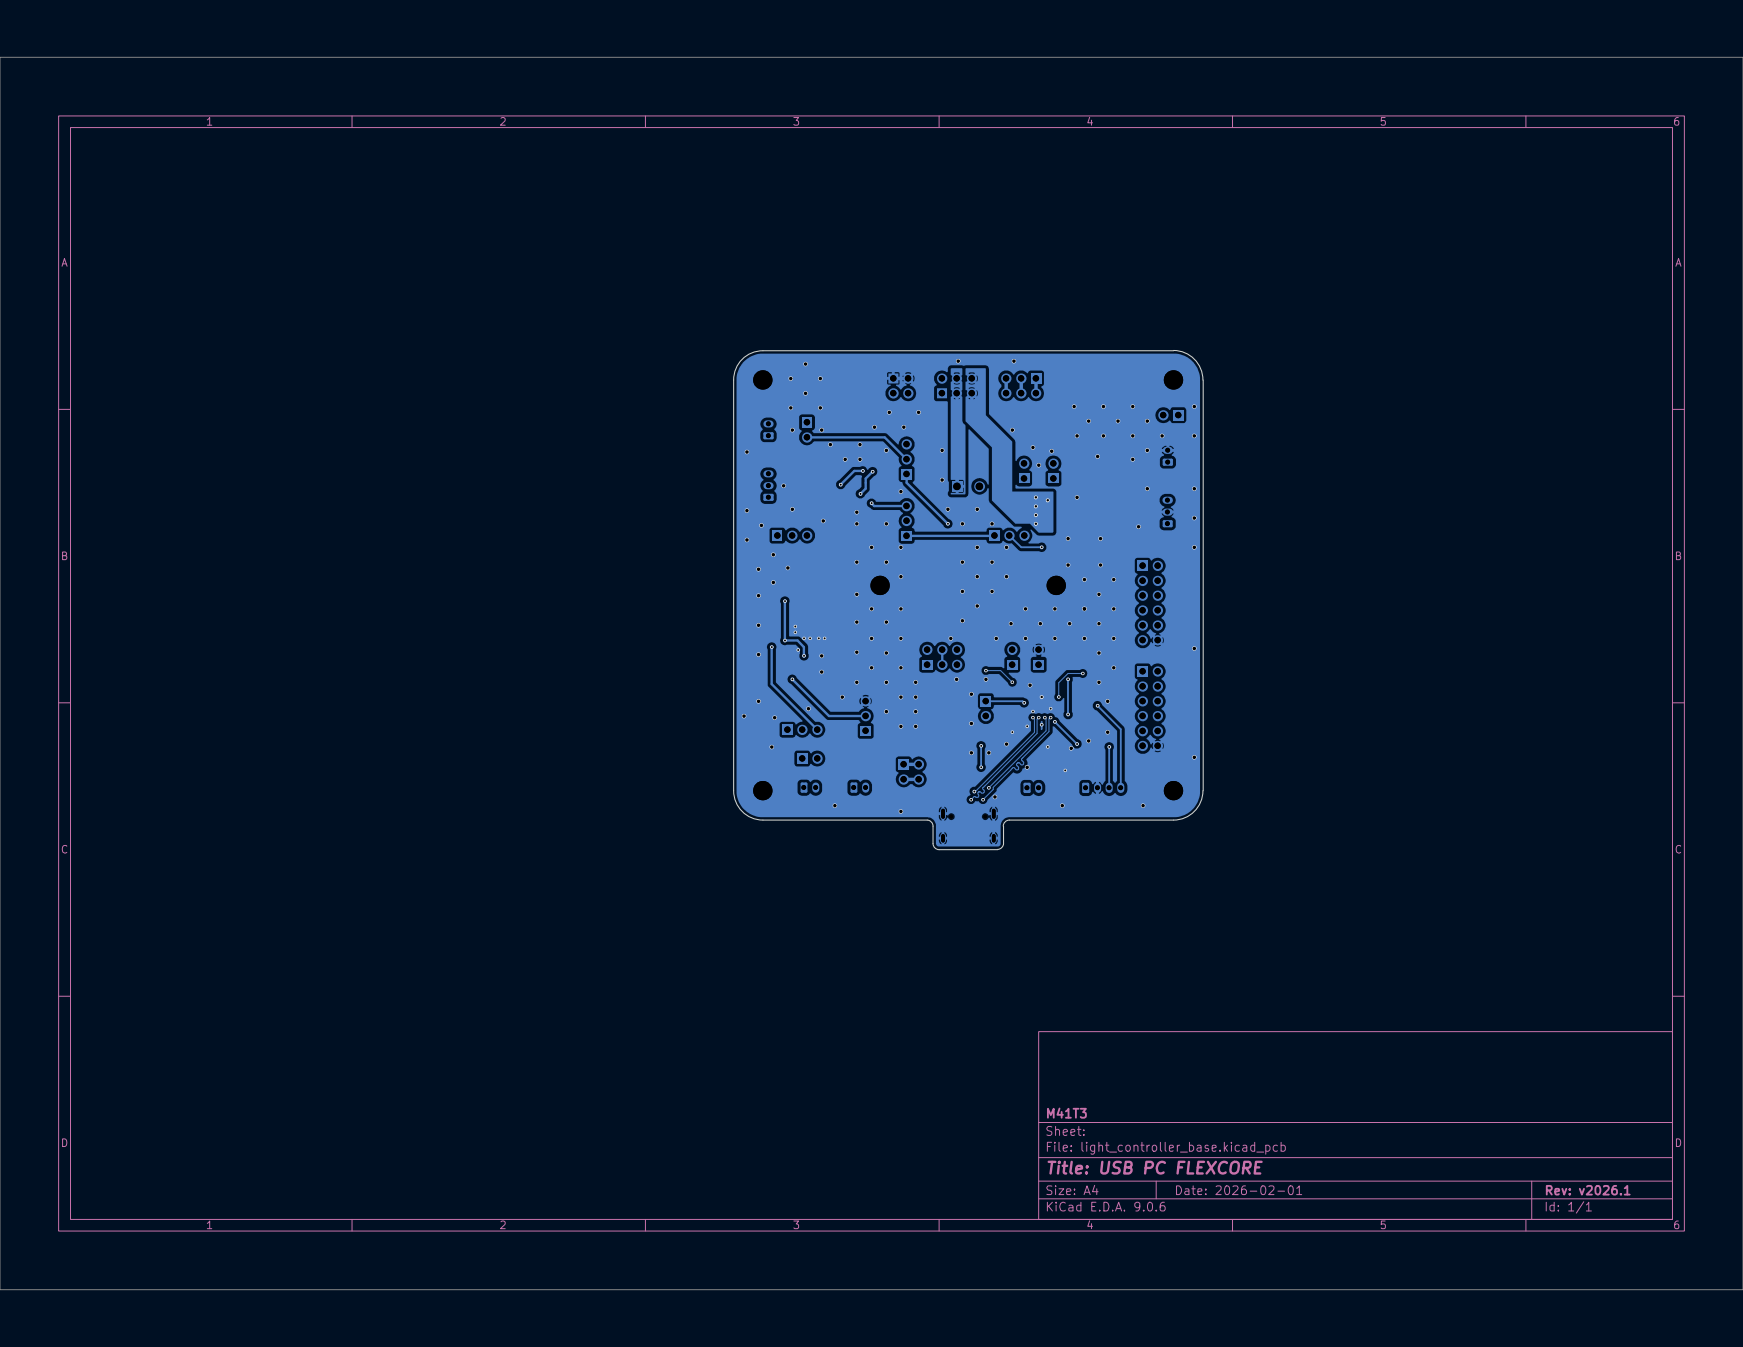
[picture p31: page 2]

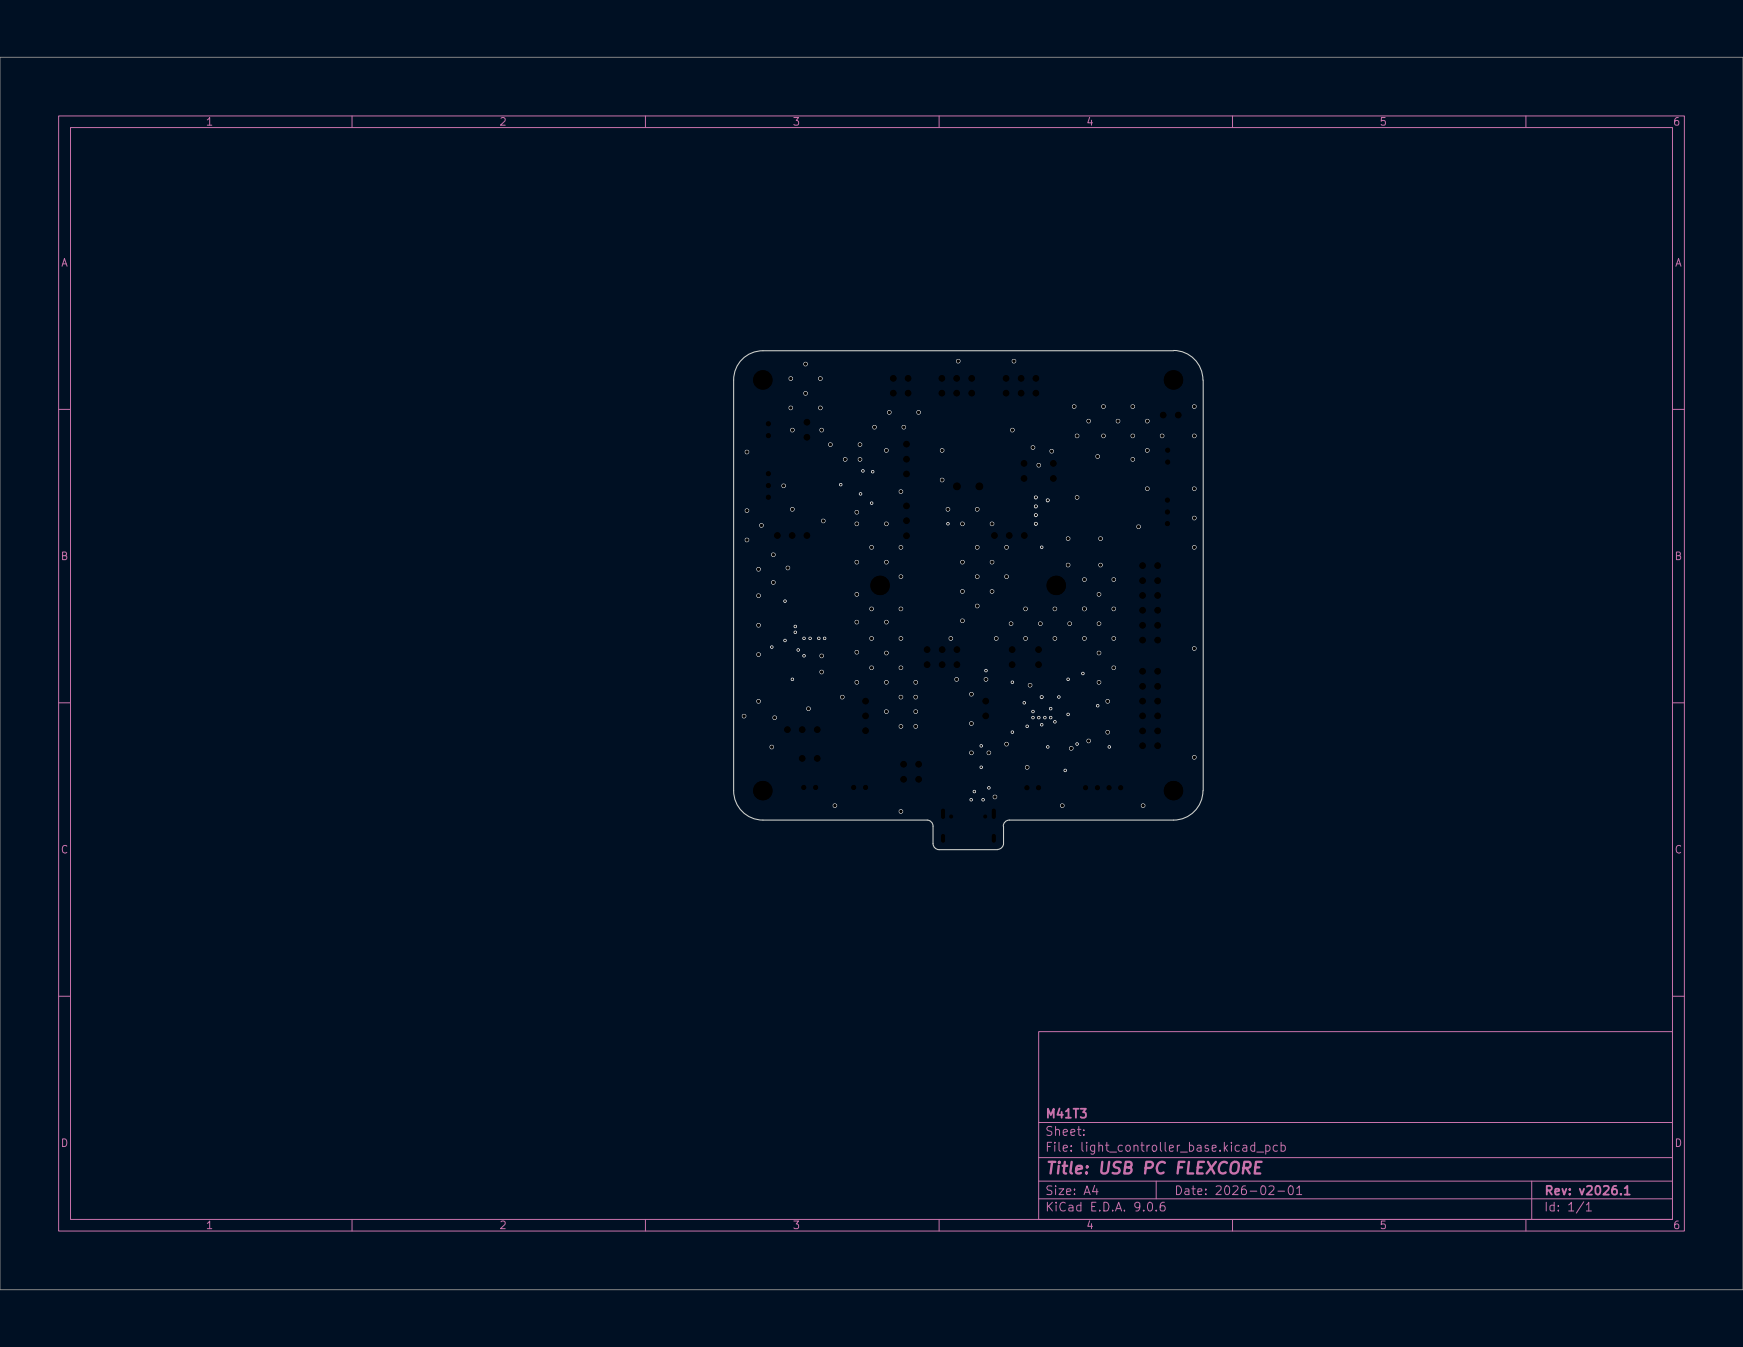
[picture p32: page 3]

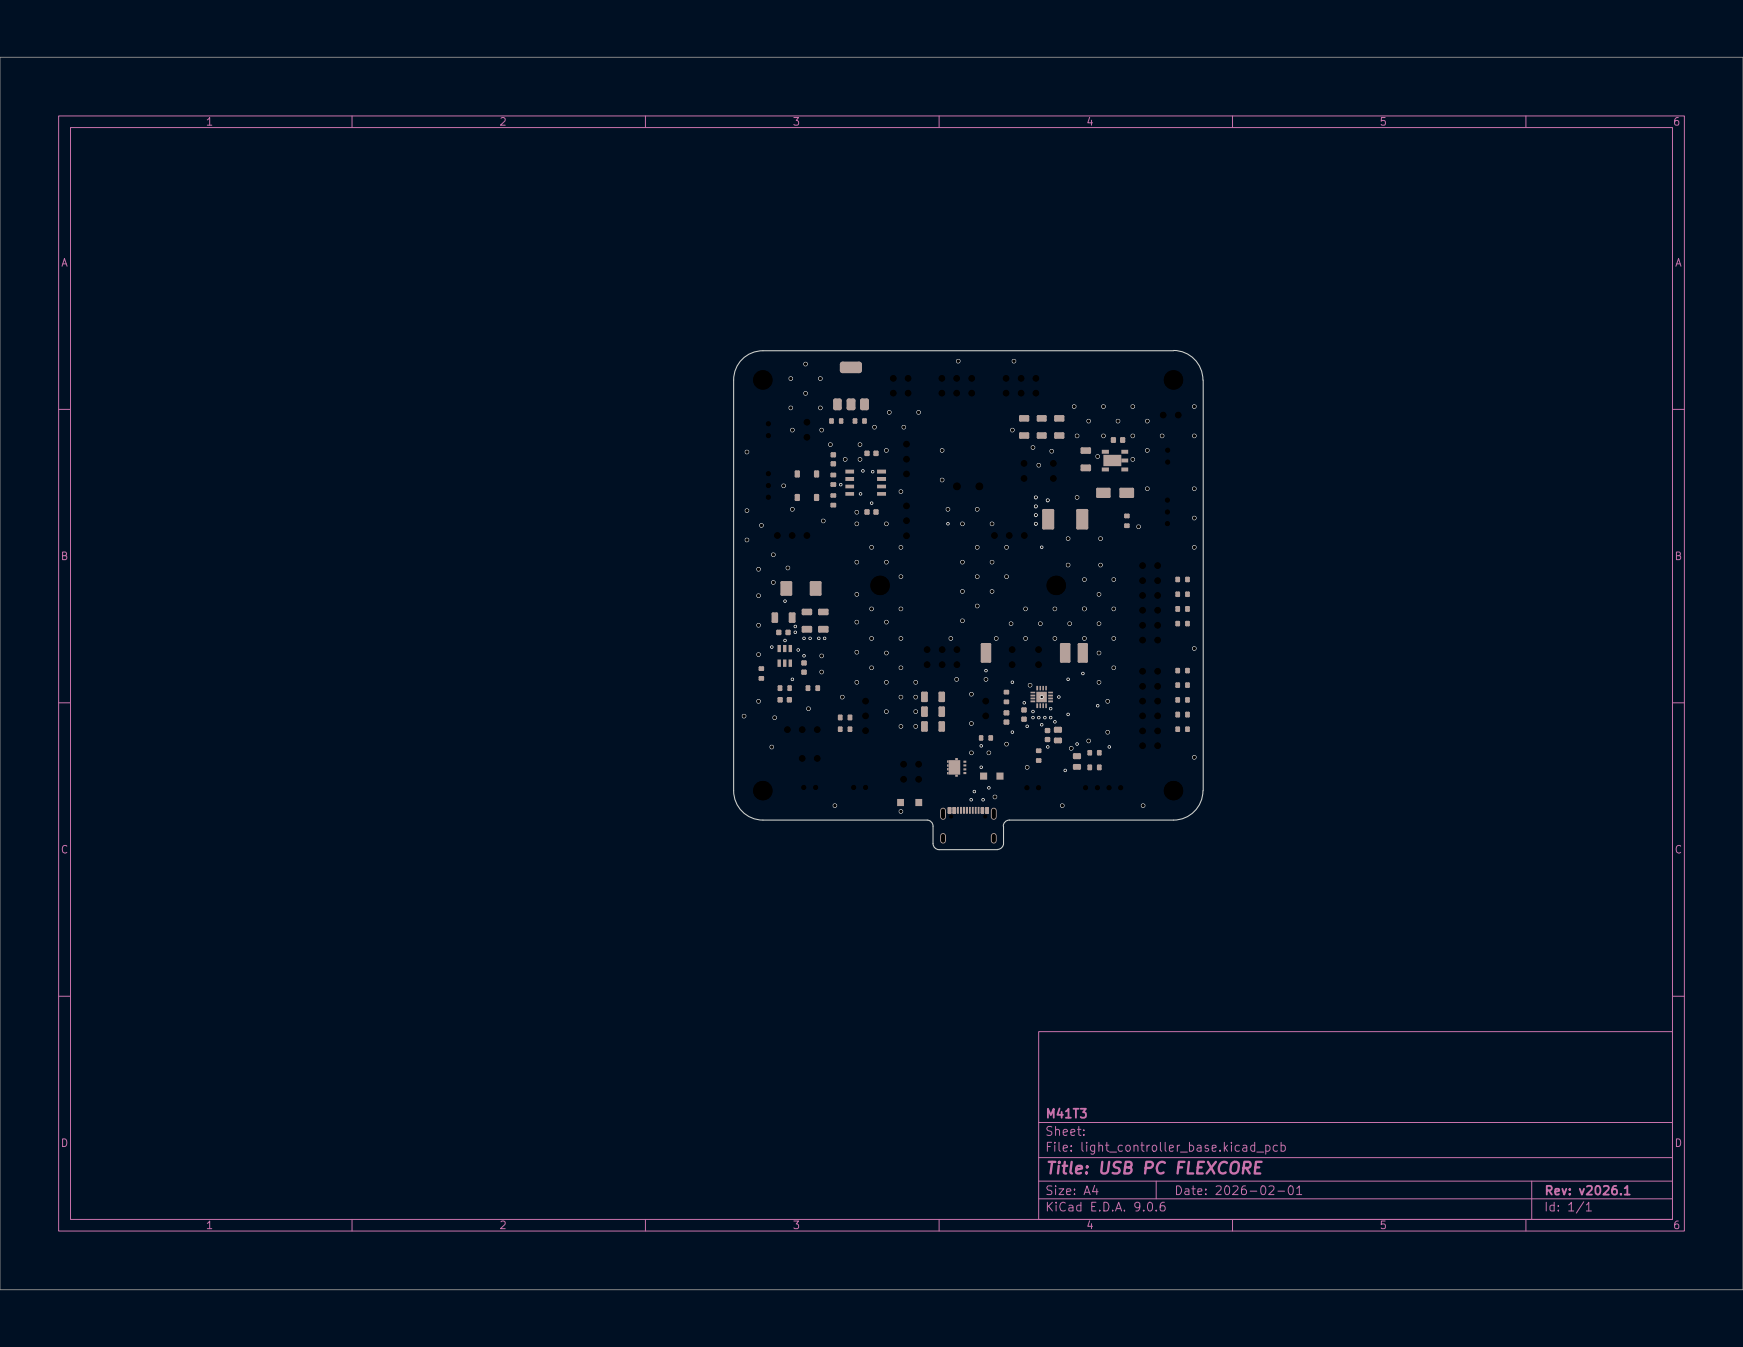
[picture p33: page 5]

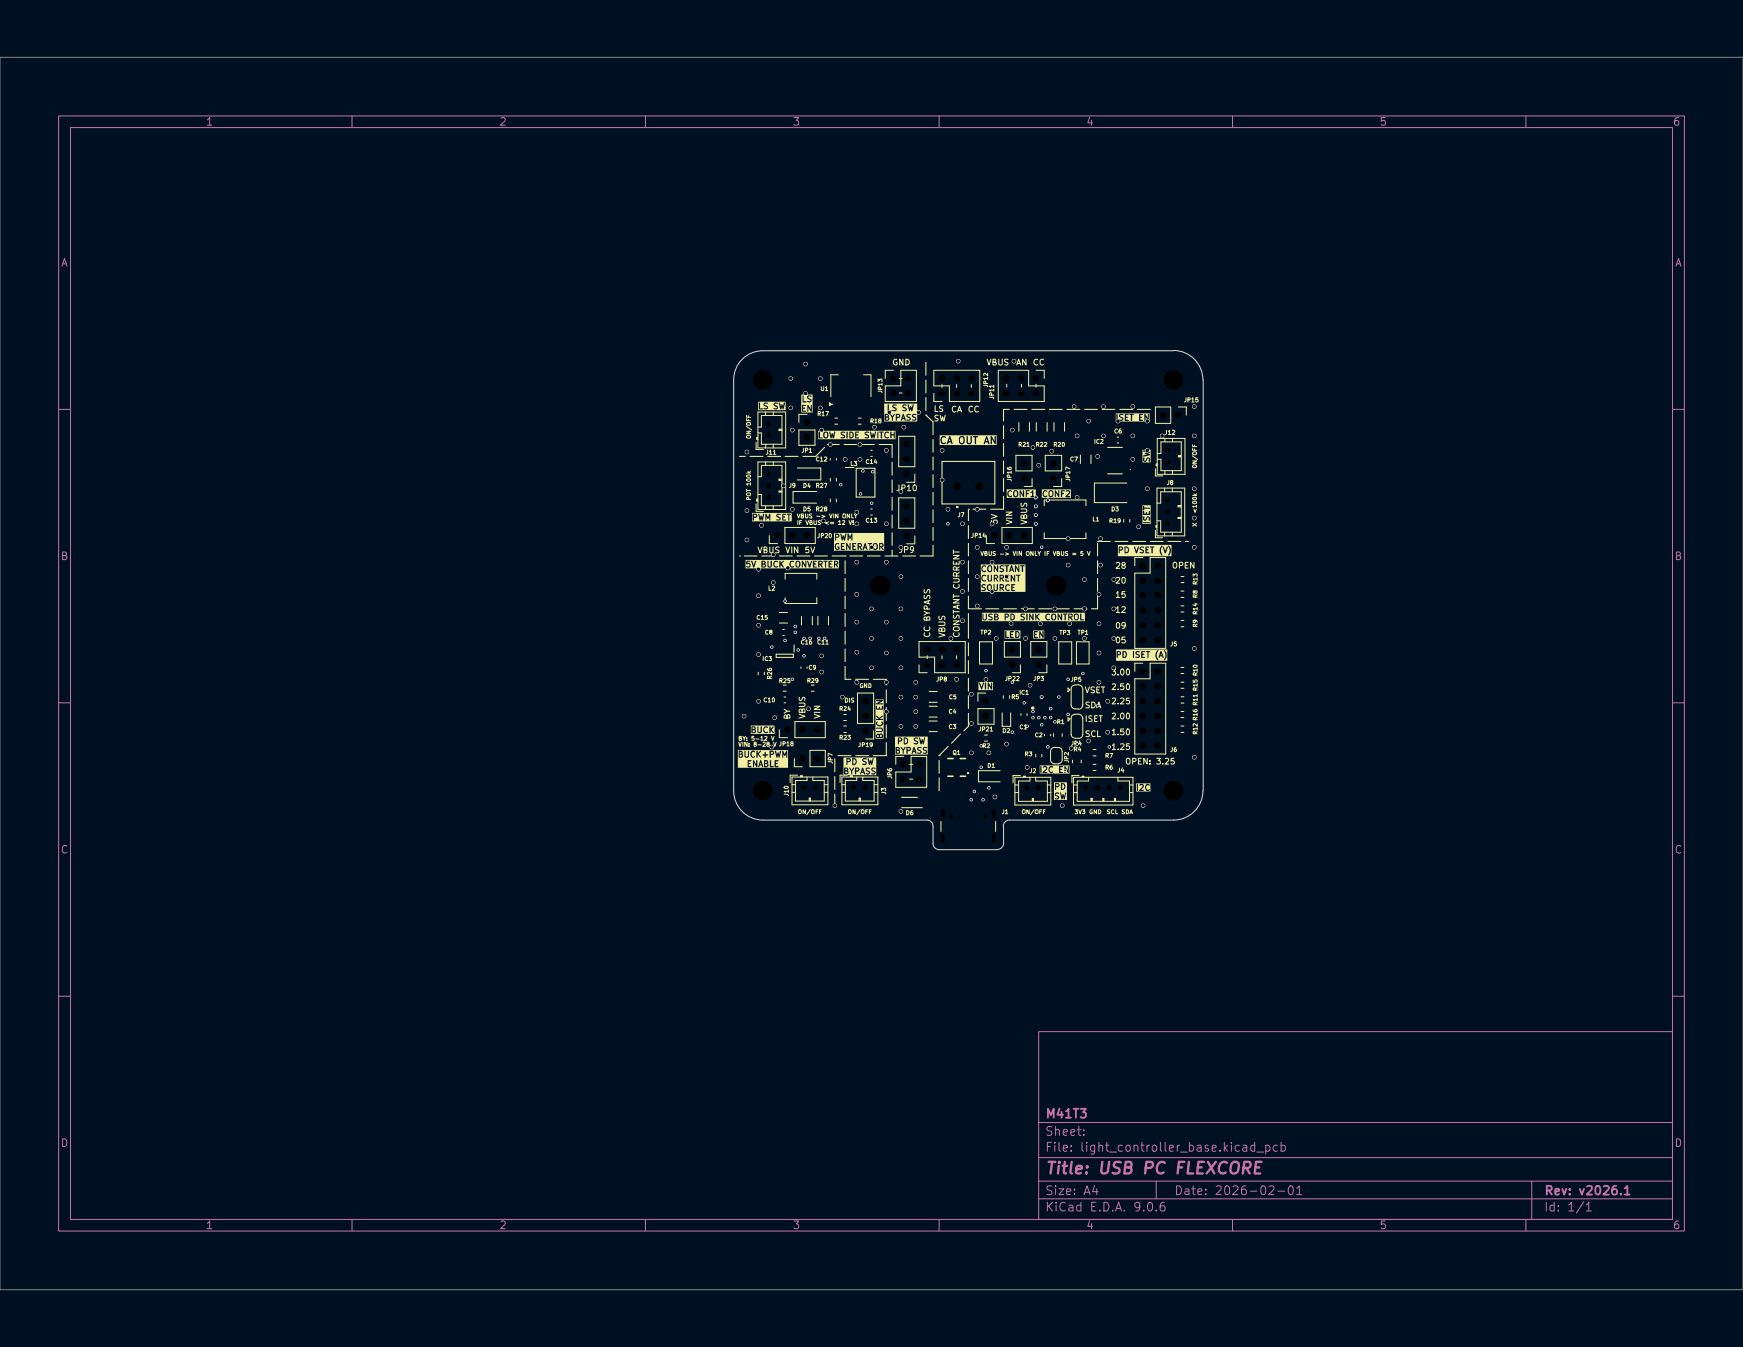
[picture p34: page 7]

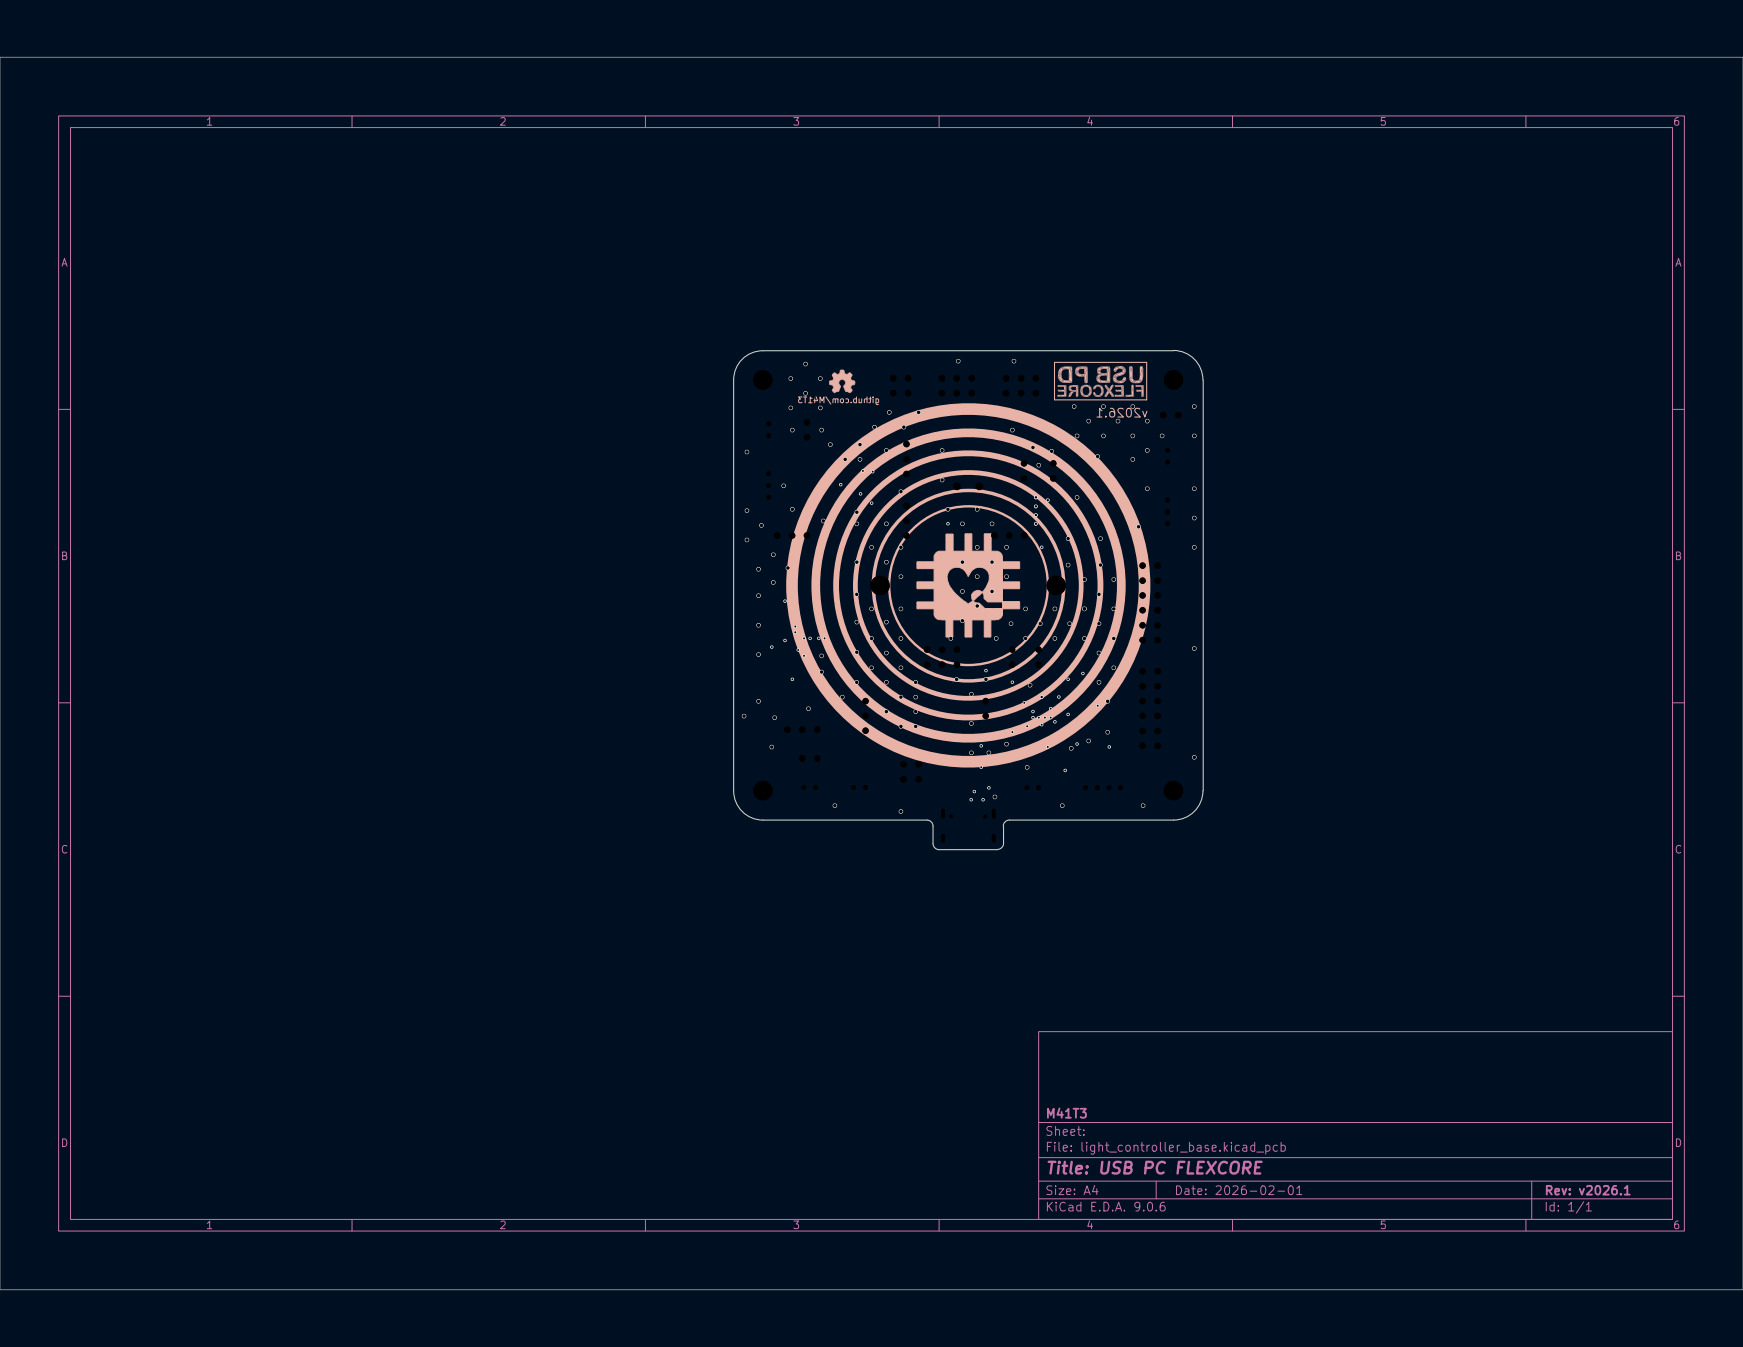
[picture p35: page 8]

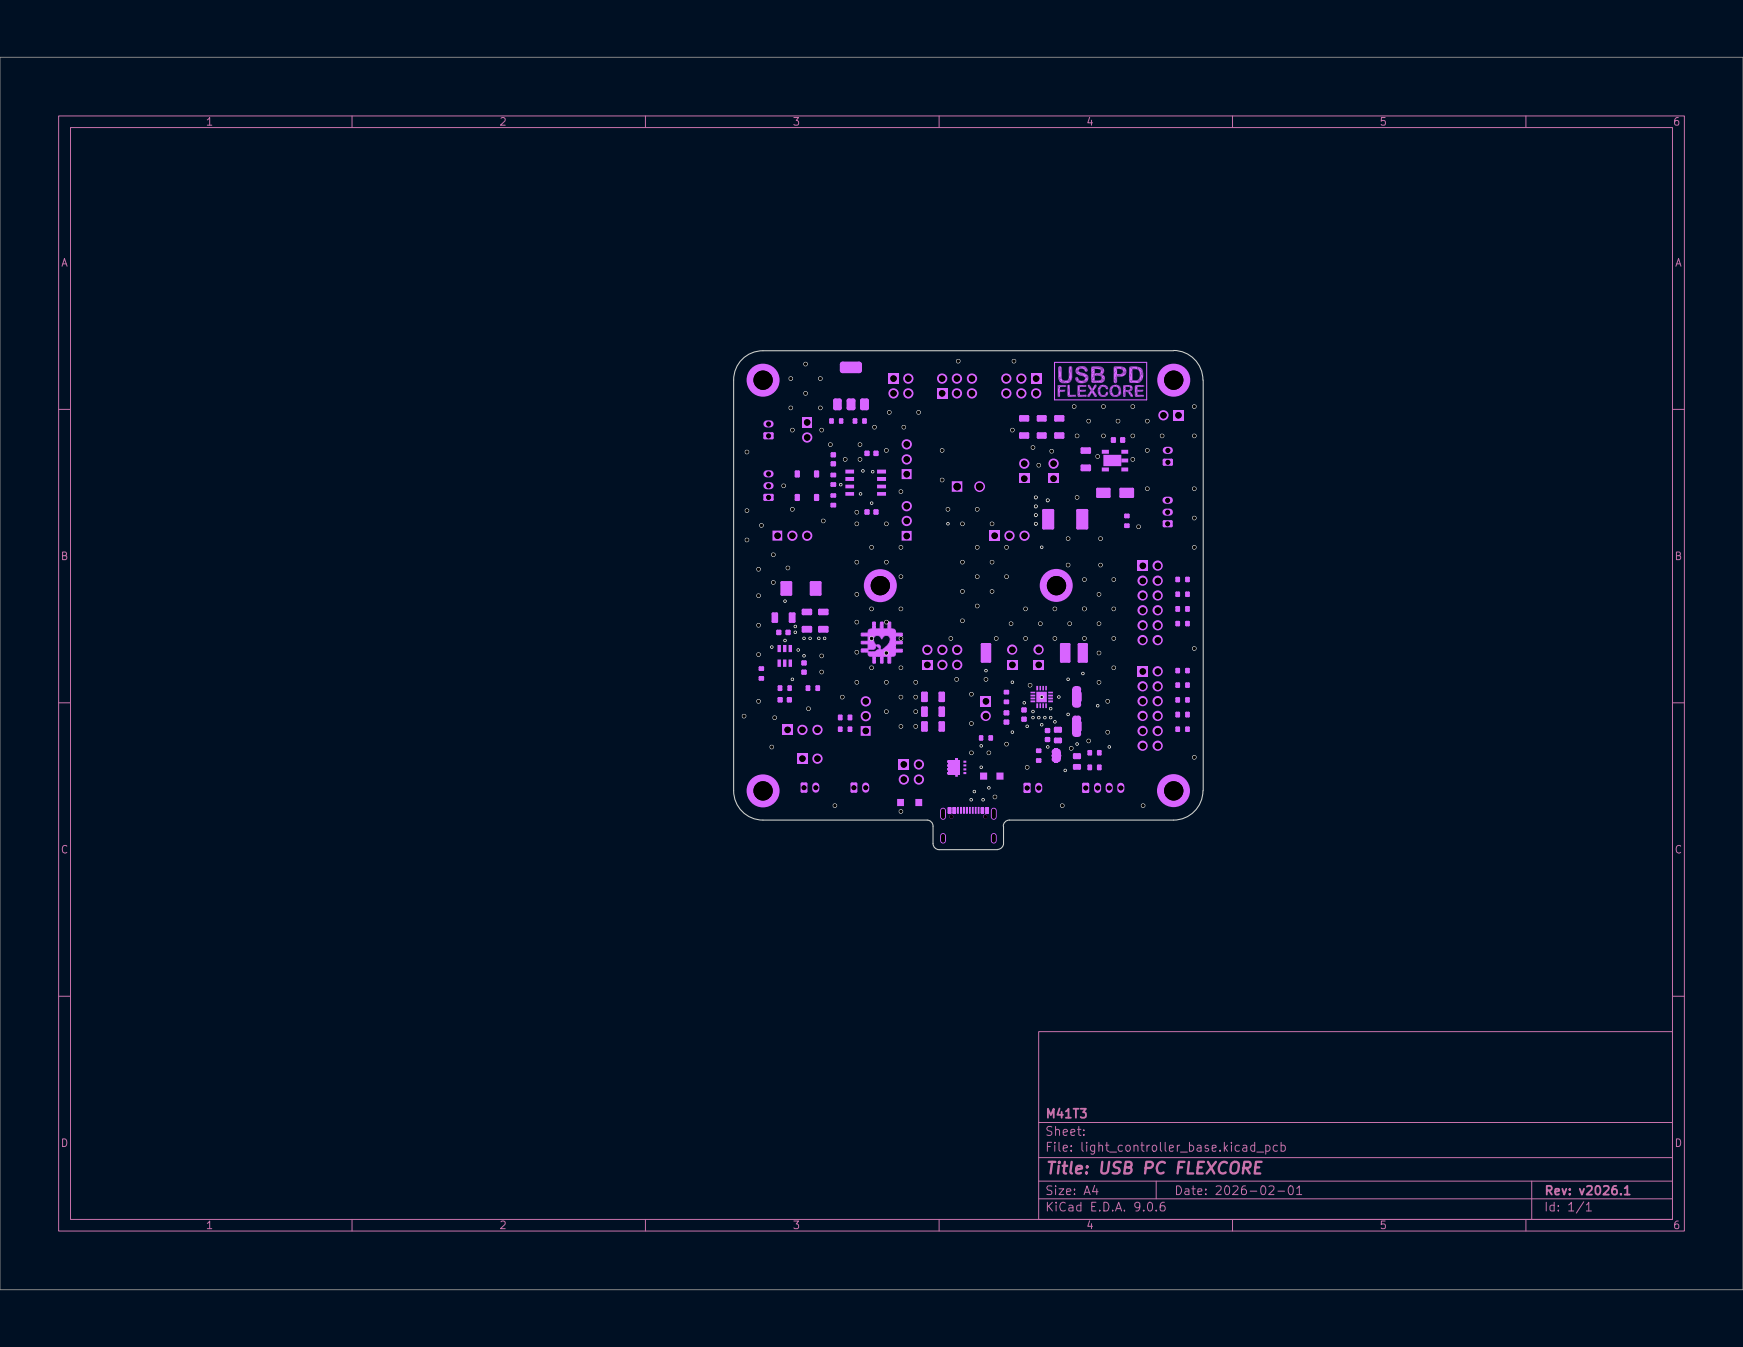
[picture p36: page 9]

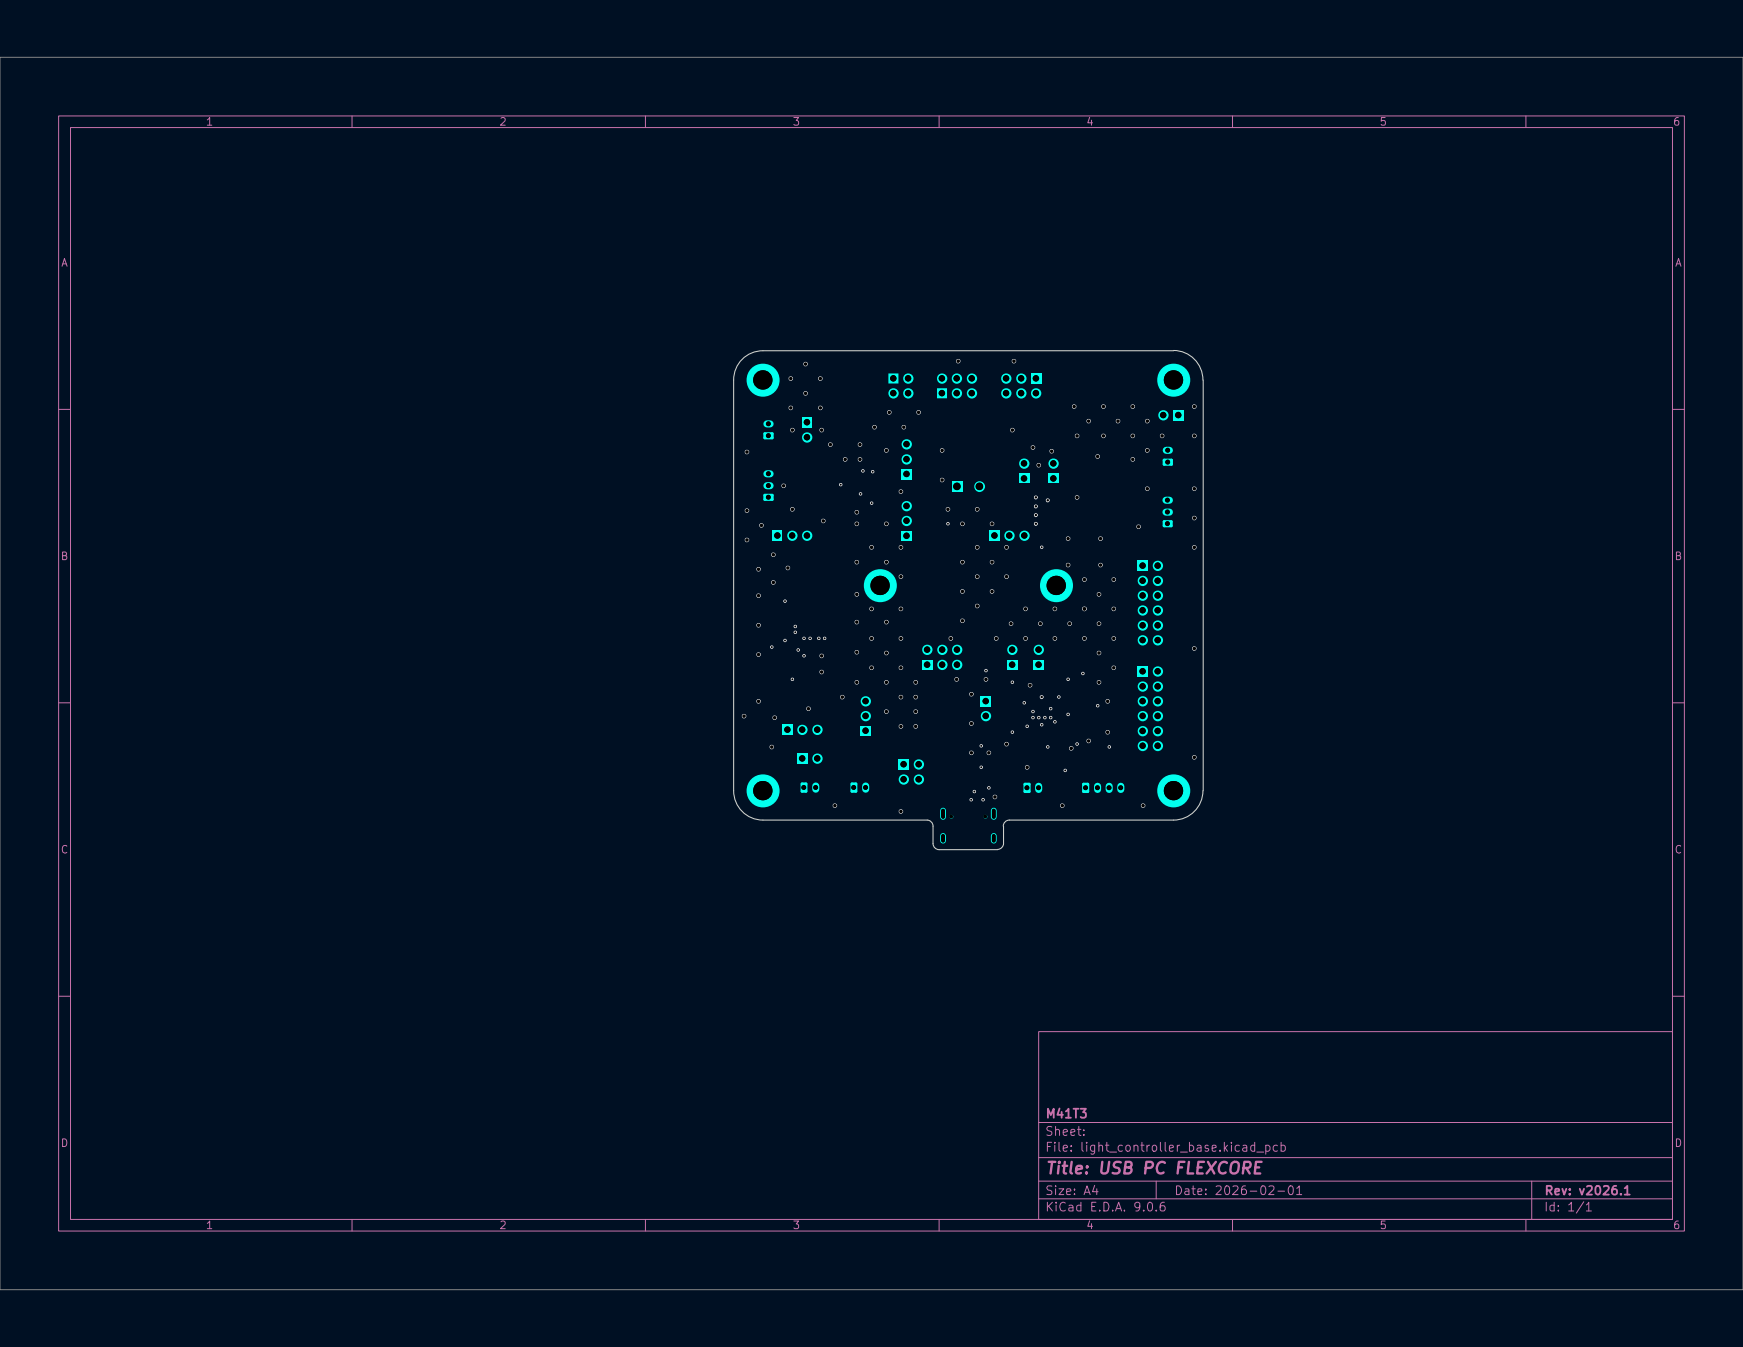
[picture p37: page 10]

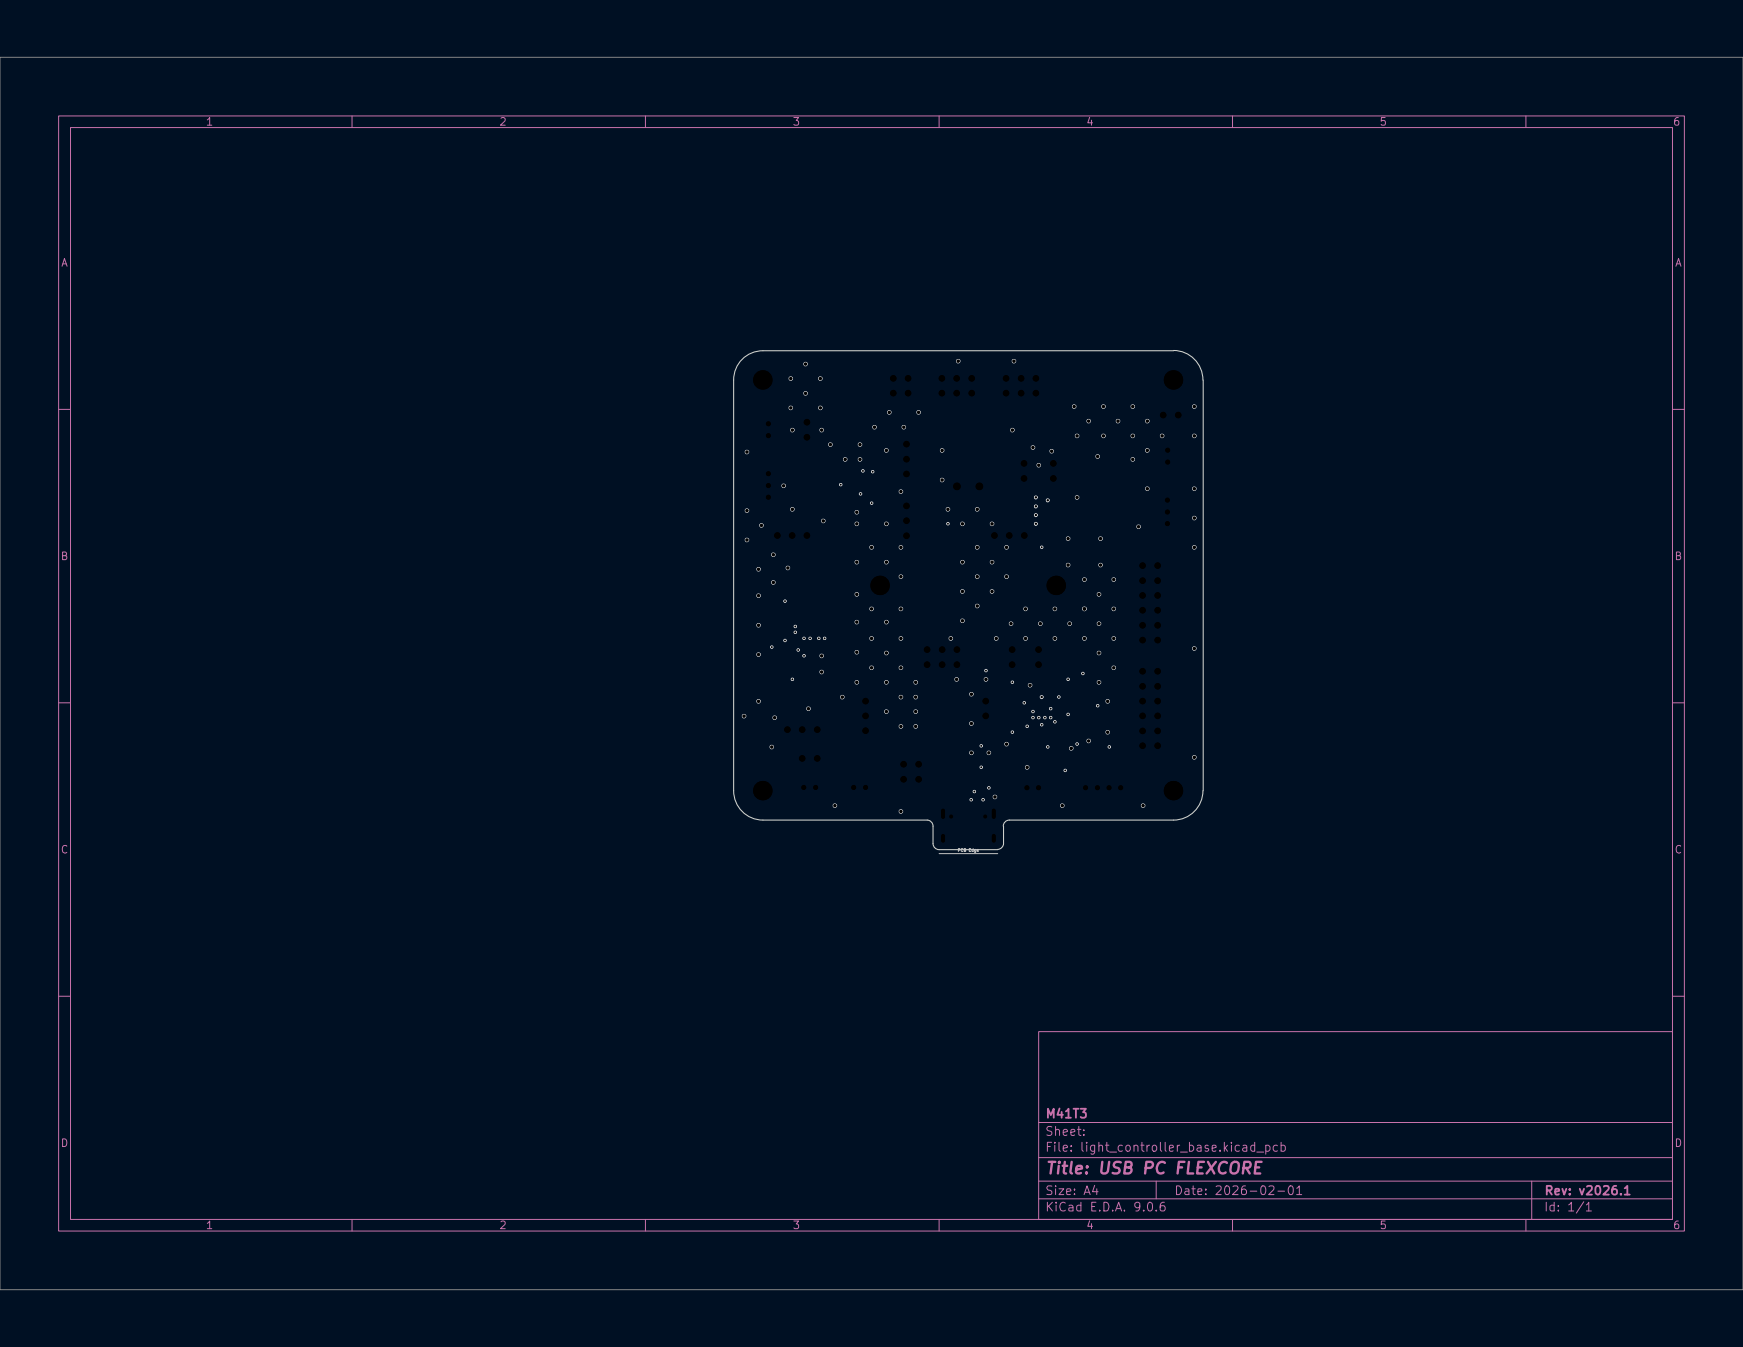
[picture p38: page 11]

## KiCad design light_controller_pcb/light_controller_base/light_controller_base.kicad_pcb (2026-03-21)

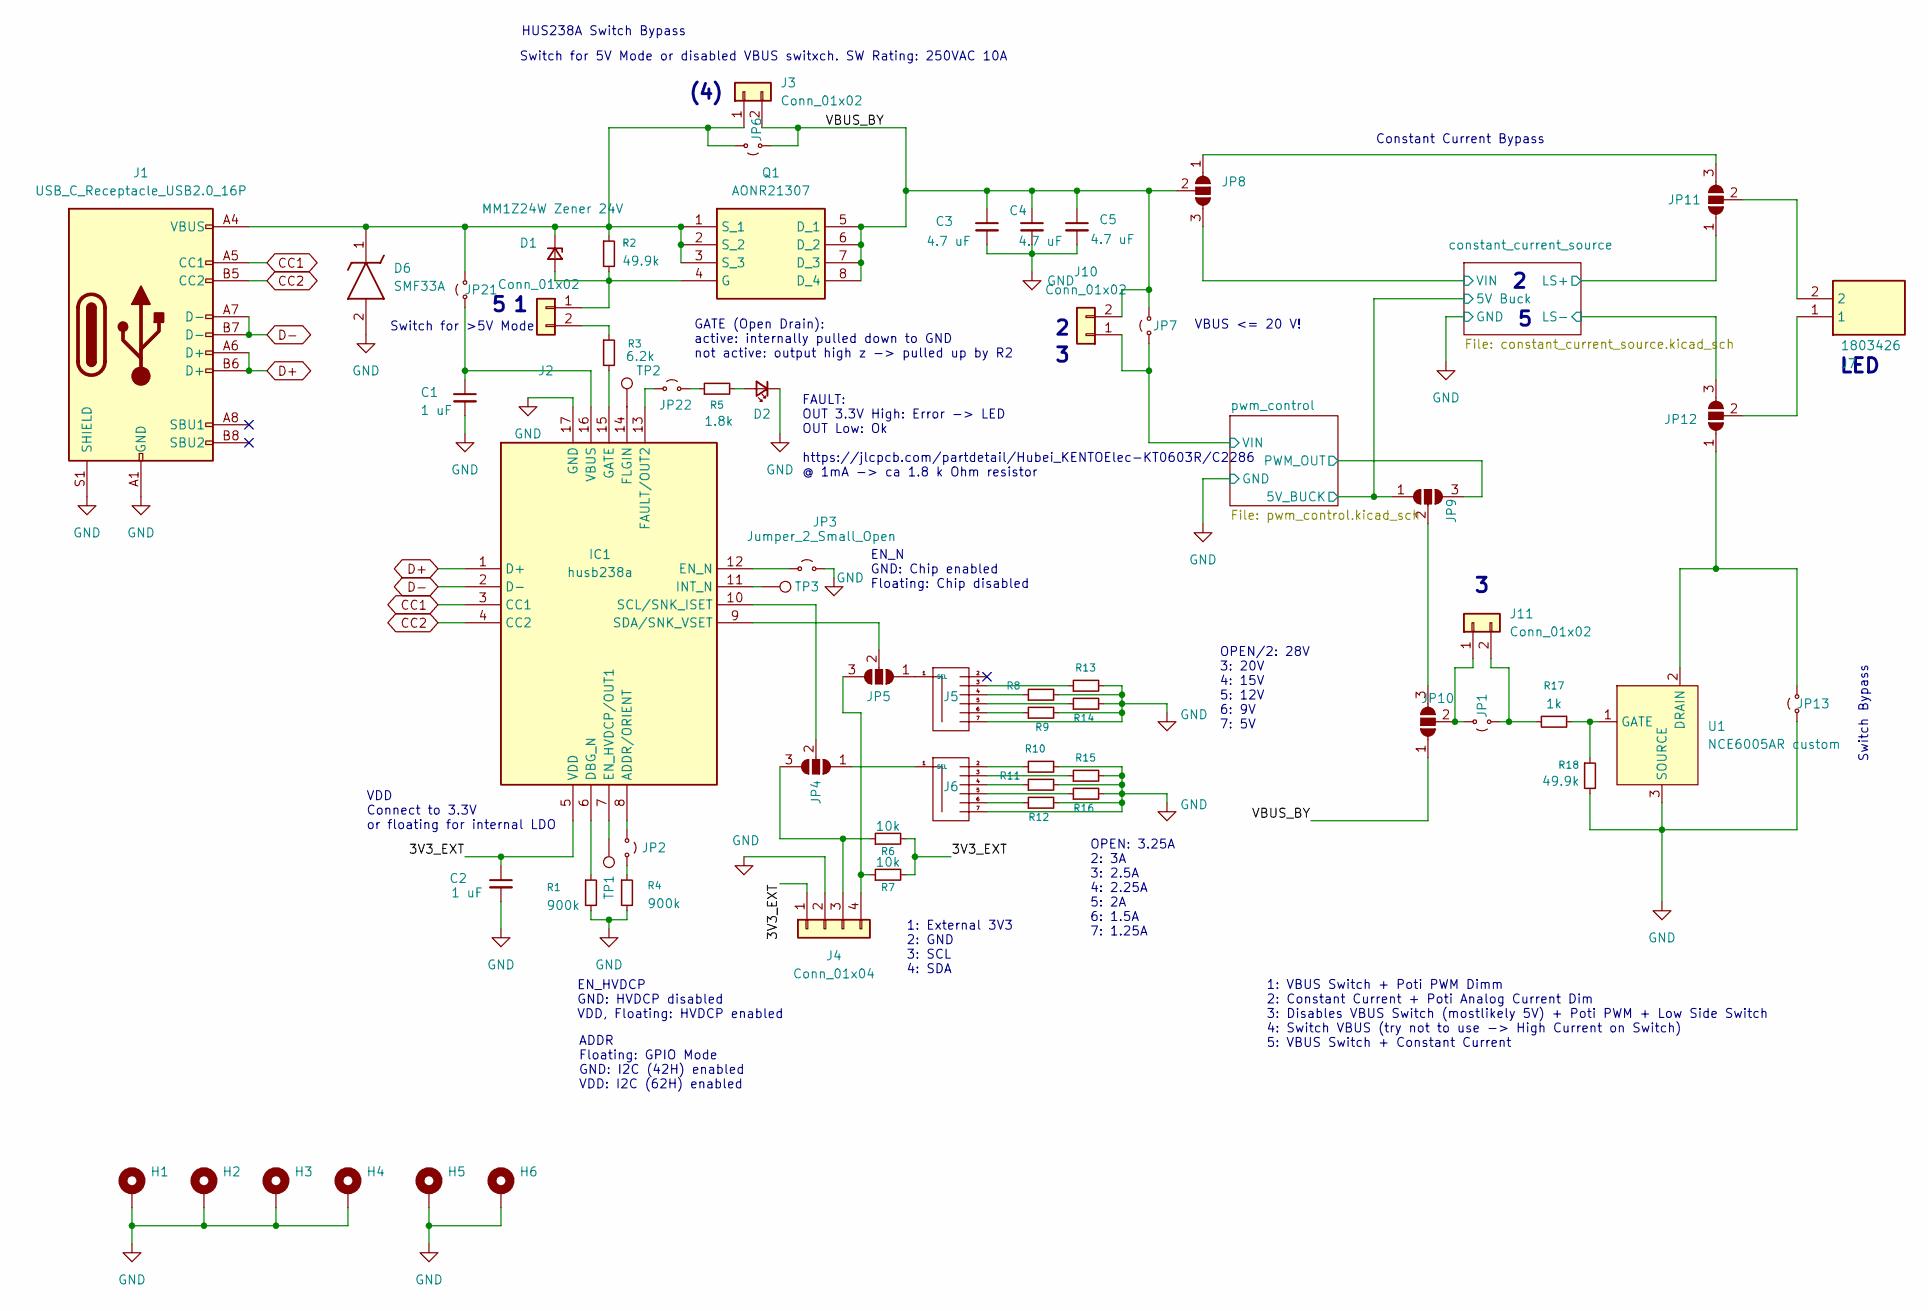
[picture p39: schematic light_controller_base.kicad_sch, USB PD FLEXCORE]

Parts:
C1, C2: 1 uF; C_0603_1608Metric; LCSC C15849
C3, C4, C5: 4.7 uF; C_1206_3216Metric; LCSC C29823
D1: MM1Z24W Zener 24V; Nexperia_CFP3_SOD-123W; LCSC C2856870
D2: LED_0603_1608Metric; LCSC C2286
D6: SMF33A; SODFL3618X110N; Manufacturer_Part_Number SMF33A; Mouser Part Number 637-SMF33A
H1, H2, H3, H4, H5, H6: MountingHole_Pad; MountingHole_3.2mm_M3_DIN965_Pad_TopBottom
IC1: husb238a; QFN50P300X300X80-17N-D; Manufacturer_Part_Number husb238a; LCSC C24833806
J1: USB_C_Receptacle_USB2.0_16P; USB_C_Receptacle_GCT_USB4105-xx-A_16P_TopMnt_Horizontal; LCSC C165948
J2, J3, J10, J11: Conn_01x02; JST_PH_B2B-PH-K_1x02_P2.00mm_Vertical
J4: Conn_01x04; JST_PH_B4B-PH-K_1x04_P2.00mm_Vertical
J5, J6: PinHeader_select_2x06_P2.54mm
J7: 1803426; Manufacturer_Part_Number 1803426; Mouser Part Number 651-1803426
JP1, JP3, JP7, JP21, JP22: Jumper_2_Small_Open; PinHeader_1x02_P2.54mm_Vertical
JP2: Jumper_2_Small_Open; SolderJumper-2_P1.3mm_Open_RoundedPad1.0x1.5mm
JP4, JP5: SolderJumper_3_Open; SolderJumper-3_P1.3mm_Bridged12_RoundedPad1.0x1.5mm
JP6, JP13: Jumper_2_Small_Open; PinHeader_doubled_2x02_P2.54mm
JP8, JP11, JP12: SolderJumper_3_Open; PinHeader_doubled_2x03_P2.54mm
JP9, JP10: SolderJumper_3_Open; PinHeader_1x03_P2.54mm_Vertical
Q1: AONR21307; DFN_3X3_EP; Manufacturer_Part_Number AONR21307; LCSC C3277813
R1, R4: 900k; R_0805_2012Metric; LCSC C52209984
R2, R18: 49.9k; R_0603_1608Metric; LCSC C23184
R3: 6.2k; R_0603_1608Metric; LCSC C4260
R5: 1.8k; R_0603_1608Metric; LCSC C4177
R6, R7: 10k; R_0603_1608Metric; LCSC C25804
R8: 11k; R_0603_1608Metric; LCSC C25950
R9: 3k; R_0603_1608Metric; LCSC C4211
R10: 21k; R_0603_1608Metric; LCSC C22956
R11: 8.45k; R_0603_1608Metric; LCSC C163417
R12: 2.26k; R_0603_1608Metric; LCSC C22904
R13: 19.1k; R_0603_1608Metric; LCSC C22897
R14, R16: 6.04k; R_0603_1608Metric; LCSC C25977
R15: 11.5k; R_0603_1608Metric; LCSC C25949
R17: 1k; R_0603_1608Metric; LCSC C21190
TP1, TP2, TP3: TestPoint; TestPoint_Keystone_5015_Micro_Mini
U1: NCE6005AR custom; SOT-223-3_TabPin2; LCSC C189606

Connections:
/3V3_EXT: C2.1, IC1.5 (VDD), J4.1, R6.2, R7.2
/VBUS_BY: C3.1, C4.1, C5.1, J3.2, J10.2, JP6.1 (A), JP7.2 (B), JP8.2 (C), JP10.1 (A), Q1.5 (D_1), Q1.6 (D_2), Q1.7 (D_3), Q1.8 (D_4)
/constant_current_source/LS+: JP11.1 (A); also elsewhere on the board
/constant_current_source/LS-: JP12.3 (B); also elsewhere on the board
/constant_current_source/VIN: JP8.3 (B); also elsewhere on the board
/pwm_control/5V: JP9.1 (A); also elsewhere on the board
/pwm_control/PWM_OUT: JP9.3 (B); also elsewhere on the board
/pwm_control/VIN: J10.1, JP7.1 (A); also elsewhere on the board
CC1: IC1.3 (CC1), J1.A5 (CC1)
CC2: IC1.4 (CC2), J1.B5 (CC2)
D+: IC1.1 (D+), J1.A6 (D+), J1.B6 (D+)
D-: IC1.2 (D-), J1.A7 (D-), J1.B7 (D-)
GND: C1.2, C2.2, C3.2, C4.2, C5.2, D2.1 (K), D6.2 (A), H1.1, H2.1, H3.1, H4.1, H5.1, H6.1, IC1.17 (GND), J1.A1 (GND), J1.A12 (GND), J1.B1 (GND), J1.B12 (GND), J1.S1 (SHIELD), J4.2, J5.7, J6.7, JP3.2 (B), JP13.1 (A), R1.2, R4.2, R8.2, R9.2, R10.2, R11.2, R12.2, R13.2, R14.2, R15.2, R16.2, R18.2, U1.3 (SOURCE); also elsewhere on the board
unnamed: D1.2 (A), J2.1, Q1.4 (G), R2.2
unnamed: D1.1 (K), D6.1 (K), J1.A4 (VBUS), J1.A9 (VBUS), J1.B4 (VBUS), J1.B9 (VBUS), J3.1, JP6.2 (B), JP21.2 (B), Q1.1 (S_1), Q1.2 (S_2), Q1.3 (S_3), R2.1
unnamed: D2.2 (A), R5.2
unnamed: IC1.8 (ADDR/ORIENT), JP2.1 (A)
unnamed: IC1.6 (DBG_N), R1.1
unnamed: IC1.7 (EN_HVDCP/OUT1), TP1.1
unnamed: IC1.12 (EN_N), JP3.1 (A)
unnamed: IC1.13 (FAULT/OUT2), JP22.1 (A)
unnamed: IC1.14 (FLGIN), TP2.1
unnamed: IC1.15 (GATE), R3.2
unnamed: IC1.11 (INT_N), TP3.1
unnamed: IC1.10 (SCL/SNK_ISET), JP4.2 (C)
unnamed: IC1.9 (SDA/SNK_VSET), JP5.2 (C)
unnamed: C1.1, IC1.16 (VBUS), JP21.1 (A)
unnamed: J2.2, R3.1
unnamed: J4.3, JP4.3 (B), R6.1
unnamed: J4.4, JP5.3 (B), R7.1
unnamed: J5.3, R13.1
unnamed: J5.4, R8.1
unnamed: J5.5, R14.1
unnamed: J5.6, R9.1
unnamed: J5.1 (SEL), JP5.1 (A)
unnamed: J6.2, R10.1
unnamed: J6.3, R15.1
unnamed: J6.4, R11.1
unnamed: J6.5, R16.1
unnamed: J6.6, R12.1
unnamed: J6.1 (SEL), JP4.1 (A)
unnamed: J11.1, JP1.2 (B), JP10.2 (C)
unnamed: J11.2, JP1.1 (A), R17.2
unnamed: JP2.2 (B), R4.1
unnamed: JP9.2 (C), JP10.3 (B)
unnamed: JP8.1 (A), JP11.3 (B)
unnamed: J7.2, JP11.2 (C)
unnamed: JP12.1 (A), JP13.2 (B), U1.2 (DRAIN)
unnamed: J7.1, JP12.2 (C)
unnamed: JP22.2 (B), R5.1
unnamed: R17.1, R18.1, U1.1 (GATE)

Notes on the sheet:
HUS238A Switch Bypass
Switch for 5V Mode or disabled VBUS switxch. SW Rating: 250VAC 10A
Switch for >5V Mode
FAULT: OUT 3.3V High: Error -> LED OUT Low: Ok https://jlcpcb.com/partdetail/Hubei_KENTOElec-KT0603R/C2286 @ 1mA -> ca 1.8 k Ohm resistor
Constant Current Bypass
1: VBUS Switch + Poti PWM Dimm 2: Constant Current + Poti Analog Current Dim 3: Disables VBUS Switch (mostlikely 5V) + Poti PWM + Low Side Switch 4: Switch VBUS (try not to use -> High Current on Switch) 5: VBUS Switch + Constant Current
OPEN: 3.25A 2: 3A 3: 2.5A 4: 2.25A 5: 2A 6: 1.5A 7: 1.25A
EN_HVDCP GND: HVDCP disabled VDD, Floating: HVDCP enabled
LED
GATE (Open Drain): active: internally pulled down to GND not active: output high z -> pulled up by R2
1: External 3V3 2: GND 3: SCL 4: SDA
OPEN/2: 28V 3: 20V 4: 15V 5: 12V 6: 9V 7: 5V
VBUS <= 20 V!
Switch Bypass
VDD Connect to 3.3V or floating for internal LDO
ADDR Floating: GPIO Mode GND: I2C (42H) enabled VDD: I2C (62H) enabled
(4)
EN_N GND: Chip enabled Floating: Chip disabled

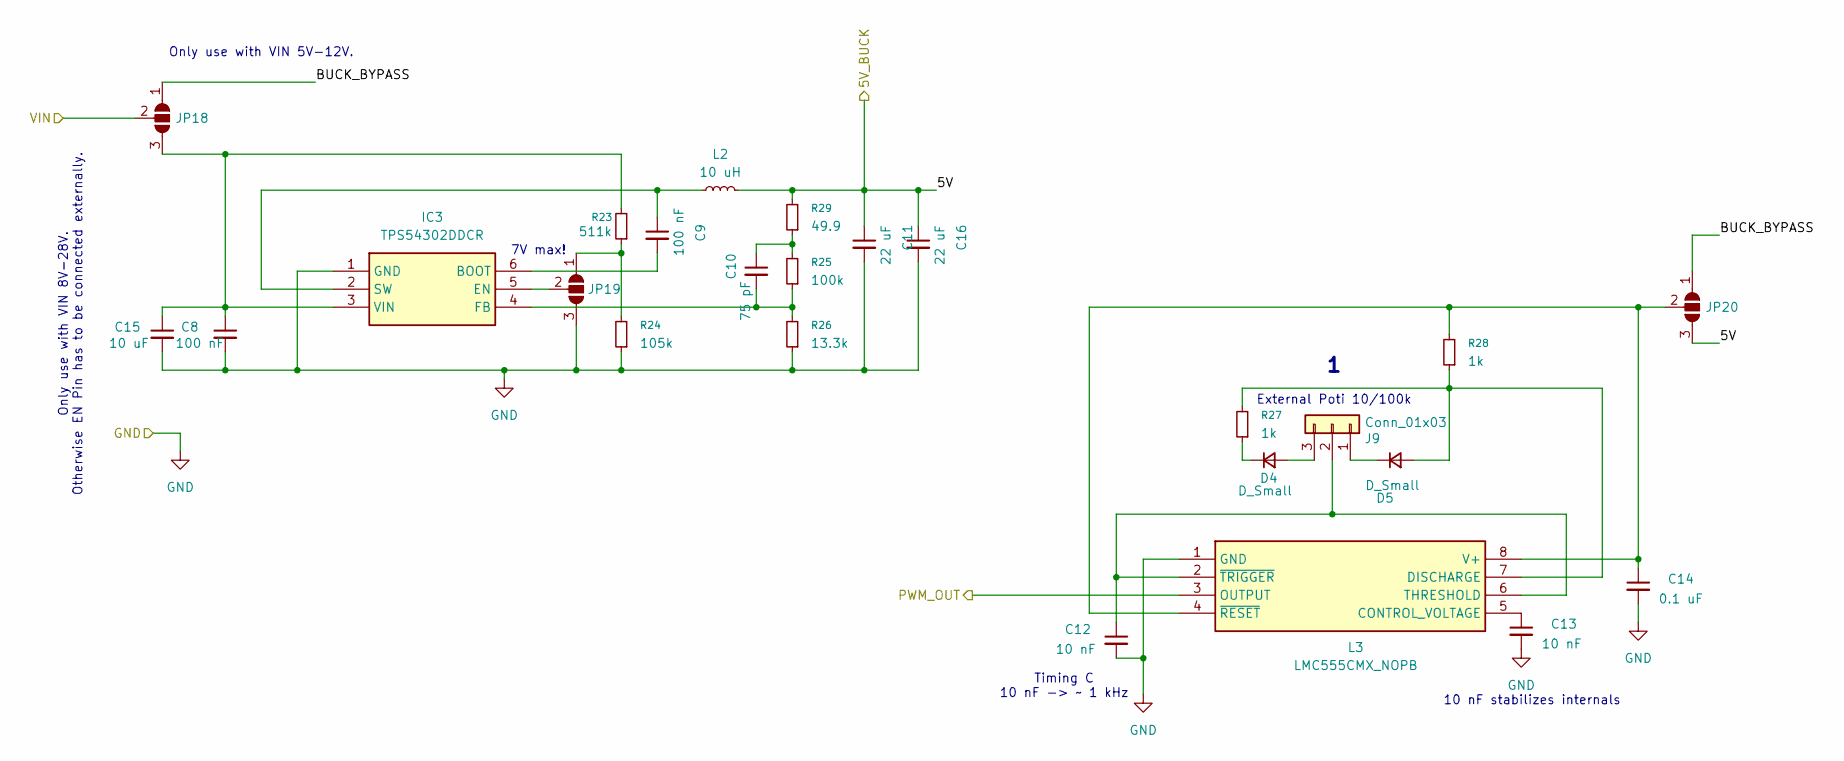
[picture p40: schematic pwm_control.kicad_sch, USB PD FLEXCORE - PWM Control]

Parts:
C8, C9: 100 nF; C_0603_1608Metric; LCSC C14663
C10: 75 pF; C_0603_1608Metric; LCSC C1681
C11, C16: 22 uF; C_1206_3216Metric; LCSC C12891
C12, C13: 10 nF; C_0603_1608Metric; LCSC C57112
C14: 0.1 uF; C_0603_1608Metric; LCSC C14663
C15: 10 uF; C_1206_3216Metric; LCSC C13585
D4, D5: D_Small; D_SOD-123; LCSC C81598
IC3: TPS54302DDCR; SOT95P280X110-6N; Manufacturer_Part_Number TPS54302DDCR; Mouser Part Number 595-TPS54302DDCR
J9: Conn_01x03; JST_PH_B3B-PH-K_1x03_P2.00mm_Vertical
JP18, JP19, JP20: SolderJumper_3_Open; PinHeader_1x03_P2.54mm_Vertical
L2: 10 uH; L_5.2_5.4_smd; LCSC C351099
L3: LMC555CMX_NOPB; SOIC127P600X175-8N; Manufacturer_Part_Number LMC555CMX/NOPB; Mouser Part Number 926-LMC555CMX/NOPB
R23: 511k; R_0603_1608Metric; LCSC C23194
R24: 105k; R_0603_1608Metric; LCSC C16840
R25: 100k; R_0603_1608Metric; LCSC C25803
R26: 13.3k; R_0603_1608Metric; LCSC C25952
R27, R28: 1k; R_0603_1608Metric; LCSC C21190
R29: 49.9; R_0603_1608Metric; LCSC C23185

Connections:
/pwm_control/5V: C11.1, C16.1, JP20.3 (B), L2.2, R29.2; also elsewhere on the board
/pwm_control/BUCK_BYPASS: JP18.1 (A), JP20.1 (A)
/pwm_control/PWM_OUT: L3.3 (OUTPUT); also elsewhere on the board
/pwm_control/VIN: JP18.2 (C); also elsewhere on the board
GND: C8.2, C11.2, C12.2, C13.2, C14.2, C15.2, C16.2, IC3.1 (GND), JP19.3 (B), L3.1 (GND), R24.1, R26.1; also elsewhere on the board
unnamed: C10.1, R25.2, R29.1
unnamed: D4.2 (A), J9.3
unnamed: D4.1 (K), R27.1
unnamed: D5.2 (A), L3.7 (DISCHARGE), R27.2, R28.1
unnamed: D5.1 (K), J9.1
unnamed: C9.2, IC3.6 (BOOT)
unnamed: IC3.5 (EN), JP19.2 (C)
unnamed: C10.2, IC3.4 (FB), R25.1, R26.2
unnamed: C9.1, IC3.2 (SW), L2.1
unnamed: C8.1, C15.1, IC3.3 (VIN), JP18.3 (B), R23.2
unnamed: C12.1, J9.2, L3.2 (~TRIGGER), L3.6 (THRESHOLD)
unnamed: JP19.1 (A), R23.1, R24.2
unnamed: C14.1, JP20.2 (C), L3.4 (~RESET), L3.8 (V+), R28.2
unnamed: C13.1, L3.5 (CONTROL_VOLTAGE)

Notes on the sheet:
Only use with VIN 5V-12V.
7V max!
Timing C 10 nF -> ~ 1 kHz
External Poti 10/100k
10 nF stabilizes internals
Only use with VIN 8V-28V. Otherwise EN Pin has to be connected externally.

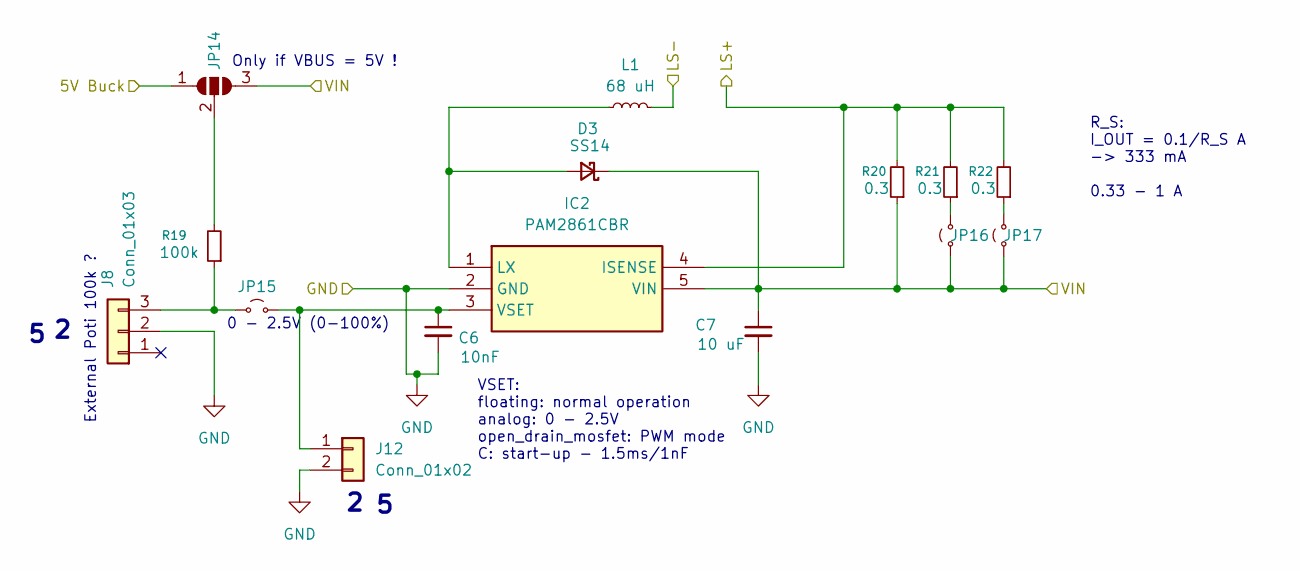
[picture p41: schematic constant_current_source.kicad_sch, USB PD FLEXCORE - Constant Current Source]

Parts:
C6: 10nF; C_0603_1608Metric; LCSC C57112
C7: 10 uF; C_1206_3216Metric; LCSC C13585
D3: SS14; D_SMA; LCSC C2480
IC2: PAM2861CBR; SOT89-5; Manufacturer_Part_Number PAM2861CBR; Mouser Part Number 621-PAM2861CBR
J8: Conn_01x03; JST_PH_B3B-PH-K_1x03_P2.00mm_Vertical
J12: Conn_01x02; JST_PH_B2B-PH-K_1x02_P2.00mm_Vertical
JP14: SolderJumper_3_Open; PinHeader_1x03_P2.54mm_Vertical
JP15, JP16, JP17: Jumper_2_Small_Open; PinHeader_1x02_P2.54mm_Vertical
L1: 68 uH; L_6.6_7.1_smd; LCSC C2983094
R19: 100k; R_0603_1608Metric; LCSC C25803
R20, R21, R22: 0.3; R_1206_3216Metric; LCSC C59882

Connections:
/constant_current_source/LS+: IC2.4 (ISENSE), R20.2, R21.2, R22.2; also elsewhere on the board
/constant_current_source/LS-: L1.2; also elsewhere on the board
/constant_current_source/VIN: C7.1, D3.1 (K), IC2.5 (VIN), JP14.3 (B), JP16.1 (A), JP17.1 (A), R20.1; also elsewhere on the board
/pwm_control/5V: JP14.1 (A); also elsewhere on the board
GND: C6.2, C7.2, IC2.2 (GND), J8.2, J12.2; also elsewhere on the board
unnamed: D3.2 (A), IC2.1 (LX), L1.1
unnamed: C6.1, IC2.3 (VSET), J12.1, JP15.2 (B)
unnamed: J8.3, JP15.1 (A), R19.1
unnamed: JP14.2 (C), R19.2
unnamed: JP16.2 (B), R21.1
unnamed: JP17.2 (B), R22.1

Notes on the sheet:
VSET: floating: normal operation analog: 0 - 2.5V open_drain_mosfet: PWM mode C: start-up - 1.5ms/1nF
External Poti 100k ?
0 - 2.5V (0-100%)
R_S: I_OUT = 0.1/R_S A -> 333 mA 0.33 - 1 A
Only if VBUS = 5V !

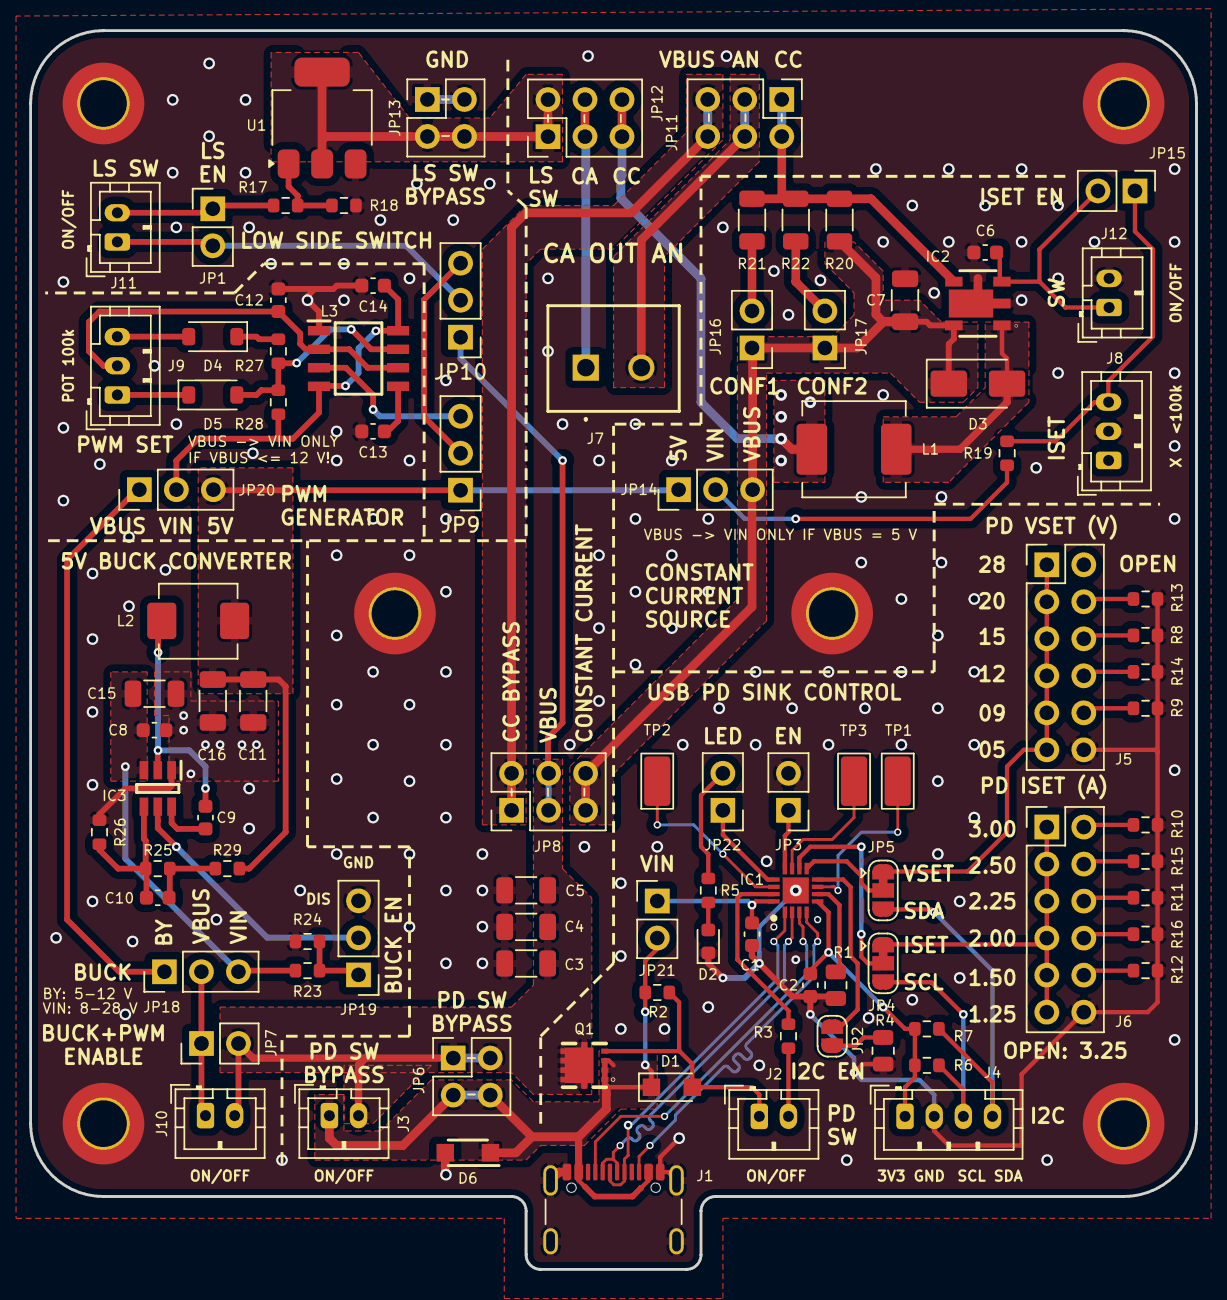
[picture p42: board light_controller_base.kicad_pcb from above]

Board: 2 copper layers, 80.0 x 85.0 mm, 102 parts (0 on the bottom side), 72 nets.

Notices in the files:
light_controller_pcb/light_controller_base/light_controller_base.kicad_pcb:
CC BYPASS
